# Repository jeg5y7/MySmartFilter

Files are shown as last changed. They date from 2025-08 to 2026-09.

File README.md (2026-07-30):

# MySmartFilter

End-to-end IoT platform for monitoring HVAC air filters. Pairs **ESP32 sensor
hardware** with a **Next.js web app** that visualises live readings, alerts
owners when a filter is loaded, and can auto-order replacements through Stripe.

Hosted at <https://mysmartfilter.com>.

See [ROADMAP.md](./ROADMAP.md) for the path to public launch.

## Features

- **Energy-cost filter model** — blower runtime is detected from ΔP (pressure
  across the filter is ~0 when the blower is off), extra electricity vs. a
  clean-filter baseline is accrued on every reading, and a replacement is
  alerted/auto-ordered once that cost meets the price of the customer's
  preferred filter. ECM (variable-speed) systems only; PSC systems use the
  pressure threshold.
- **Device fleet management** — pair / rename / relocate / delete ESP32 devices
  through a 4-step setup wizard with QR scanning and captive-portal WiFi
  onboarding.
- **Live sensor dashboard** — differential pressure, temperature, humidity, CO₂
  and VOC readings rendered with Recharts (selectable time range, status chips).
- **Filter alerts** — per-device pressure threshold, configurable auto-order
  delay, in-app alert management page.
- **Email notifications** via Resend — device-offline alerts and auto-order
  confirmations with templated HTML.
- **Auto-replenishment** — Stripe Checkout for one-off orders plus a scheduled
  job that opens auto-orders when a filter alert ages past its grace window.
- **Public REST API (`/api/v1/*`)** — Bearer `sk_live_…` keys, managed under
  `/settings`.
- **Outbound webhooks** — HMAC-signed `filter.alert`, `device.offline`, and
  `reading.threshold` events with a delivery log.
- **OTA firmware updates** — `/api/ota/check` + `/api/ota/download` consumed by
  the `esp32-ota` PlatformIO environment.
- **CSV export** — download a device's full reading history.
- **Scheduled jobs** via Vercel Cron — device-offline sweep and auto-order
  processor.

## Stack

| Layer | Tech |
|---|---|
| Framework | Next.js 15 (App Router) + React 19 |
| API | tRPC 11 + TanStack Query, plus REST under `/api/*` |
| Auth | NextAuth v5 (Resend magic-link provider) + Prisma adapter |
| DB | PostgreSQL via Prisma 6 |
| Payments | Stripe Checkout + webhooks |
| Email | Resend |
| Charts / UI  | Recharts, Tailwind v4 |
| Validation | Zod, `@t3-oss/env-nextjs` |
| Firmware | ESP32 / PlatformIO (envs: `esp32-dev`, `-prod`, `-test`, `-ota`) |
| Hosting | Vercel (Hobby plan — crons are daily) |

## Repository layout

```
src/
  app/
    api/
      auth/            NextAuth route handlers
      device/          ESP32 + dashboard device endpoints
      sensor/          Sensor ingest (POST)
      cron/            device-offline, auto-order
      ota/             check, download
      export/          CSV export
      store/           Stripe checkout + webhook
      user/            Account settings
      v1/devices/      Public REST API
      trpc/            tRPC handler
    dashboard/         Authenticated dashboard
    devices/           Device list + detail
    setup/             Device pairing wizard
    settings/          API keys, webhooks, notifications
    store/             Filter shop, orders, success
    signin/            Magic-link sign-in
  server/
    api/routers/       post, sensor, user, device, firmware, integrations
    auth/              NextAuth config + custom Prisma adapter
    db.ts              Prisma client singleton
  lib/                 energy, filter-alerts, filter-preference, api-key,
                       resend, stripe, stripe-client, webhooks
  trpc/                Client / server tRPC plumbing
prisma/
  schema.prisma        Device, SensorReading, FilterAlert, Order, …
  seed.ts              Seed data
esp32/
  platformio.ini       Multi-environment build config
  src/                 Firmware (captive portal, SDP810 driver, main)
```

## Local development

### Prerequisites

- Node 20+ (`package.json` pins `npm@10.9.2`)
- PostgreSQL 15+ — `./start-database.sh` spins up a Docker container
- A Resend account (for sign-in emails)
- A Stripe account (test mode works)

### Setup

```bash
git clone https://github.com/jeg5y7/MySmartFilter.git
cd MySmartFilter
cp .env.example .env          # fill in values, see below
./start-database.sh           # optional Docker postgres
npm install
npm run db:push               # apply Prisma schema
npm run db:seed               # optional seed data
npm run dev                   # http://localhost:3000
```

### Environment variables

Required for the app to boot:

| Variable | Notes |
|---|---|
| `DATABASE_URL` | Postgres connection string |
| `AUTH_SECRET` | `npx auth secret` |
| `RESEND_API_KEY`  | Magic-link sign-in + alert emails  |
| `EMAIL_FROM` | e.g. `noreply@mysmartfilter.com` |

Required for the store and scheduled jobs (all validated in `src/env.js`):

| Variable | Notes |
|---|---|
| `STRIPE_SECRET_KEY` | Server-side Stripe |
| `STRIPE_WEBHOOK_SECRET` | Used by `/api/store/webhook` |
| `NEXT_PUBLIC_STRIPE_PUBLISHABLE_KEY` | Client-side |
| `CRON_SECRET` | Bearer token Vercel sends to crons |
| `NEXTAUTH_URL` / `AUTH_URL` | Base URL for Stripe redirects |

### Useful scripts

```bash
npm run dev          # next dev --turbo
npm run build        # production build
npm run typecheck    # tsc --noEmit
npm run lint         # next lint
npm run check        # lint + typecheck
npm run db:push      # sync schema to DB
npm run db:generate  # prisma migrate dev
npm run db:migrate   # prisma migrate deploy
npm run db:studio    # Prisma Studio UI
npm run db:seed      # run prisma/seed.ts
```

## Firmware

The `esp32/` workspace uses PlatformIO. Select an environment per target:

```bash
cd esp32
pio run -e esp32-dev    # localhost:3000
pio run -e esp32-prod   # mysmartfilter.com
pio run -e esp32-test   # fake sensor data, no hardware
pio run -e esp32-ota    # OTA-capable build
```

The captive-portal flow lets a fresh device be configured from a phone with no
hardcoded credentials. After pairing, the device POSTs to `/api/sensor` using a
Bearer `sf_…` API token issued by `/api/device/register`.

See `esp32/PLATFORMIO_GUIDE.md` for hardware bring-up.

## Deployment

Built for Vercel:

1. Provision a Postgres database (Vercel Postgres / Neon / Supabase).
2. Add the env vars above in **Project Settings → Environment Variables**.
3. Configure a Stripe webhook pointing at `/api/store/webhook` and copy the
   signing secret into `STRIPE_WEBHOOK_SECRET`.
4. Verify the Resend domain — see `RESEND_DNS_SETUP.md` and
   `VERCEL_DNS_RECORDS.md`.
5. Vercel reads `vercel.json` for the cron schedule.

## REST API v1

```
GET /api/v1/devices
Authorization: Bearer sk_live_<hex>
```

Manage keys at `/settings`. Each key tracks `lastUsed` for auditing.

Webhook payloads are signed with HMAC-SHA256:

```
X-SmartFilter-Event: filter.alert
X-SmartFilter-Signature: sha256=<HMAC of body using webhook.secret>
```

## Known issues / TODO

- Crons run daily (Vercel Hobby limit). Handlers are schedule-agnostic, but
  offline alerts and auto-orders can lag up to 24 h — upgrade to Pro and set
  `*/15` / hourly schedules before launch (see ROADMAP Phase 3).
- Auto-orders create `pending` orders but don't charge a card yet — off-session
  Stripe payment is ROADMAP Phase 2.
- Firmware doesn't yet send the `deviceSecret` on register; legacy devices are
  claimable by the first secret presenter (ratchet upgrade path).

## License

Private project — all rights reserved.

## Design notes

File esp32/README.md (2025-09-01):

# Smart Filter Monitor - ESP32 Firmware

This Arduino code monitors your filter's differential pressure using an SDP810 sensor and sends data to mysmartfilter.com for real-time tracking and predictive maintenance.

## Hardware Requirements

- ESP32 DevKit v1
- SDP810 Differential Pressure Sensor
- Jumper wires for I2C connections

## Wiring Diagram

| ESP32 Pin | SDP810 Pin | Description |
|---|---|---|
| 3.3V | VDD | Power supply |
| GND | GND | Ground |
| GPIO 21 | SDA | I2C Data |
| GPIO 22 | SCL | I2C Clock |

## Arduino IDE Setup

1. **Install ESP32 Board Package:**
   - File → Preferences
   - Add this URL to Additional Board Manager URLs:
     ```
     https://dl.espressif.com/dl/package_esp32_index.json
     ```
   - Tools → Board → Boards Manager
   - Search "ESP32" and install "ESP32 by Espressif Systems"

2. **Install Required Libraries:**
   - Sketch → Include Library → Manage Libraries
   - Install these libraries:
     - `ArduinoJson` by Benoit Blanchon
     - `WiFi` (usually pre-installed)
     - `HTTPClient` (usually pre-installed)

## Configuration

### 1. WiFi Settings
Update these lines in `sensor_monitor.ino`:
```cpp
const char* ssid = "Your_WiFi_Name";
const char* password = "Your_WiFi_Password";
```

### 2. User ID Configuration
To get your User ID:

1. **Sign in to your app** at https://mysmartfilter.com
2. **Open browser developer tools** (F12)
3. **Go to Application/Storage → Local Storage**
4. **Look for user session data** or...
5. **Use this temporary method:**

Add this tRPC query to your app to get user IDs:

```typescript
// In your app, add this to get user ID
console.log("User ID:", session?.user?.id);
```

Then update the ESP32 code:
```cpp
const char* userId = "your_actual_user_id_here";
```

### 3. Device ID (Optional)
You can customize the device identifier:
```cpp
const char* deviceId = "SmartFilter_YourLocation";
```

## Upload Instructions

1. **Connect ESP32** to your computer via USB
2. **Select Board:** Tools → Board → ESP32 Dev Module
3. **Select Port:** Tools → Port → (your ESP32 port)
4. **Upload:** Sketch → Upload

## Monitoring

1. **Open Serial Monitor:** Tools → Serial Monitor
2. **Set baud rate to 115200**
3. **Watch for:**
   - WiFi connection status
   - Sensor readings
   - API response messages

## Troubleshooting

### WiFi Issues
- Check SSID and password
- Ensure 2.4GHz WiFi (ESP32 doesn't support 5GHz)
- Check signal strength

### Sensor Issues
- Verify I2C wiring
- Check sensor power (3.3V)
- Try different I2C addresses if needed

### API Issues
- Verify user ID is correct
- Check internet connection
- Monitor serial output for HTTP errors

## Sample Serial Output

```
ESP32 Sensor Monitor Started
Device ID: SmartFilter_001
WiFi connected!
IP address: 192.168.1.100
SDP810 sensor initialized successfully

=== Sensor Reading ===
Pressure: 125.3 Pa
Temperature: 23.5 °C
Sending: {"pressure":125.3,"temperature":23.5,"deviceId":"SmartFilter_001","userId":"user123"}
HTTP Response: 200
Response: {"success":true,"data":{"id":"abc123","timestamp":"2025-08-13T04:00:00.000Z"}}
✓ Data sent successfully
```

## Next Steps

1. **Test locally** with serial monitor
2. **Verify data appears** in your web dashboard
3. **Adjust reading interval** if needed (currently 30 seconds)
4. **Add error handling** for production use

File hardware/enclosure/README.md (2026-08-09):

# Rev A enclosure — 3D-printable

Two variants, both parametric CadQuery models:

- **USB-powered (current pilot direction)** — `enclosure_usb.py` →
  `base-usb.stl` / `lid-usb.stl` / `enclosure-usb.step`.
  **116.8 × 46.8 × 28.4 mm.** No battery bay; the dev board's USB port
  faces a 16 × 10 mm wall opening, so the power cable plugs straight into
  the board. Tubes enter the opposite end.
- **Battery (parked with Rev B firmware)** — `enclosure.py` →
  `base.stl` / `lid.stl` / `enclosure.step`. **136.8 × 60.8 × 31.4 mm**
  with a 3×AA bay and a grommeted power-cable hole.

Everything below applies to both unless noted.

## Print settings (Bambu Studio)

| Setting | Value |
|---|---|
| Material | **PETG** (handles furnace-room temps better than PLA) |
| Layer height | 0.2 mm |
| Walls | 3 |
| Infill | 15 % gyroid |
| Supports | **None needed** |
| Orientation | base: cavity up (as imported) · lid: top face down (as imported) |
| Plate | textured PEI, no brim needed |

Import both STLs into one plate — combined print is roughly 3–4 h on a P1/X1.

## What goes where

- **USB variant power**: route a micro-USB/USB-C cable through the wall
  opening straight into the dev board — no internal power wiring at all
- **Battery bay** (battery variant only — large fence, left): flat 3×AA
  holder (~58×48×16 mm), drops in; dab of hot glue or foam tape to stop
  rattle
- **ESP32 bay** (long fence, front-right): 30-pin dev board drops in flat
- **Sensor bay** (small fence, back-right): SDP810 sits inside; the kit's
  two tubes pass through the **two grommeted holes in the right end wall**
  (Ø7.6 — fits a standard 8 mm rubber grommet with tube through it)
- **Power** (Ø8.2 hole, front wall): adapter cable enters over the ESP32
  bay; knot the cable inside as a strain relief
- **Magnets**: 4 × Ø12×3 mm neodymium discs glue into the pockets on the
  **outside bottom** (CA or E6000, flush = full grip on the furnace cabinet;
  adhesive pad is the backup for non-steel cabinets)
- **Lid**: 12 mm panel-mount momentary button + 5 mm LED press into the two
  lid holes; skirt drops into the cavity; 4 × #4 × ½″ self-tapping screws
  into the corner posts

## Tweaking the fit

Everything is a named parameter at the top of `enclosure.py` (bay sizes,
hole diameters, wall thickness, magnet size…). Change a number, rerun:

```bash
pip install cadquery
python hardware/enclosure/enclosure.py
```

First-print checklist: verify your battery holder and dev-board footprints
against `BAT_L/BAT_W` and `ESP_L/ESP_W` before slicing — clone boards vary
by a millimeter or two.

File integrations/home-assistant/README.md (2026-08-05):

# MySmartFilter × Home Assistant

Brings your smart filter monitor into Home Assistant: filter life, pressure
drop, temperature, battery, wasted-energy cost, and a **Replace filter**
problem sensor you can automate on.

## Install (manual, ~2 minutes)

1. Copy `custom_components/mysmartfilter/` into your Home Assistant
   `config/custom_components/` folder.
2. Restart Home Assistant.
3. **Settings → Devices & Services → Add Integration → MySmartFilter.**
4. Paste an API key from
   [mysmartfilter.com → Settings → Integrations](https://www.mysmartfilter.com/settings/integrations).

Each monitor appears as a device with these entities:

| Entity | What it is |
|---|---|
| `sensor.<name>_filter_life` | % of filter value remaining (100 = fresh) |
| `sensor.<name>_filter_pressure_drop` | Live ΔP across the filter (Pa) |
| `sensor.<name>_temperature` | Utility-room temperature |
| `sensor.<name>_battery` | Battery % (battery models) |
| `sensor.<name>_wasted_energy_cost` | ¢ of extra electricity this filter has cost |
| `sensor.<name>_blower_runtime` | Blower hours on this filter |
| `binary_sensor.<name>_replace_filter` | On when replacement saves money |

## Example automation

```yaml
automation:
  - alias: "Filter needs replacing — light the hallway lamp red"
    trigger:
      - platform: state
        entity_id: binary_sensor.furnace_replace_filter
        to: "on"
    action:
      - service: light.turn_on
        target: { entity_id: light.hallway }
        data: { color_name: red }
```

## Notes

- Cloud-polling every 2 minutes via the public API (`GET /api/v1/devices`).
- Battery monitors upload hourly, so their values step hourly — alerts still
  push to your email/phone immediately via the MySmartFilter cloud.
- HACS: this folder will move to a dedicated repository for HACS listing;
  manual install works today.

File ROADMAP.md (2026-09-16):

# MySmartFilter — Launch Roadmap

**Goal:** public launch in ~3 months.
**Business model:** razor-and-blades with a freemium split — buy the monitor
and get live data free (dashboard + smart home); enroll in **Filter AutoShip**
(automatic filter shipping) to unlock the energy-savings calculation,
historical trending, and advanced HVAC diagnostics (future). No separate
subscription fee — filters are the revenue.
**Fulfillment (launch):** manual dropship from an admin order queue.

## Tier enforcement ✅

- [x] Server-side gates: history queries clamp to a 1-hour live window for
  free accounts (`sensor.getByTimeRange`), CSV export is member-only (403)
- [x] UI: Filter Health card shows a locked/upsell state for free tier;
  chart ranges beyond 1h are locked with an AutoShip hint; Export hidden
- [x] v1 API: `plan` field; energy-model outputs (filterLifePct,
  filterStatus, runtimeHours, extraEnergyCostCents) are null on free —
  HA integration degrades gracefully (live sensors work, premium unknown)
- [x] Device LED: button press replays server's filter verdict (solid =
  OK, 3 slow blinks = soon, 6 fast = replace) cached from batch responses

## Phase 0 — Production blockers ✅

- [x] Delete unauthenticated `GET /api/sensor` and `/api/debug-env`
- [x] Validate Stripe/cron env vars through `src/env.js`
- [x] Remove public `sensor.create` tRPC mutation (unauthenticated write)
- [x] `/api/device/register` token leak — device-secret handshake
  (firmware presents a self-generated secret to re-fetch its token)
- [x] Offline sweep made schedule-agnostic (works on daily Hobby cron)
- [x] Fix filter-preference resolution (device-specific → user default)

## Phase 1 — Energy-cost model ✅

The core product promise: replace the filter when the extra electricity it
burns exceeds the price of a new one.

- [x] `src/lib/energy.ts` — physics: `extraWatts = ΔP_rise × airflow / η`,
  blower runtime detected from ΔP > 5 Pa (pressure is ~0 when the blower is off)
- [x] Per-reading accrual of runtime + extra cost on ingest
- [x] Clean-filter baseline auto-captured on first blower-on reading
- [x] Energy-cost alert → email → 24 h grace → auto-order — both blower
  types: ECM accrues direct extra blower watts; PSC accrues the
  system-runtime penalty (less airflow → less capacity → compressor and all
  run longer to satisfy the thermostat)
- [x] HVAC settings UI (blower type, airflow CFM, electricity rate)
- [x] Filter Health card with cost-vs-price progress meter
- [x] "I replaced my filter" reset flow

**Deploy note:** run `npm run db:push` (or a migration) — `Device` gained
`deviceSecretHash`, `blowerType`, `airflowCfm`, `electricityRateCents`,
`baselineDeltaP`, `filterInstalledAt`, `runtimeHours`,
`extraEnergyCostCents`, `lastAccrualAt`.

## Phase 2 — Money movement ✅

- [x] Saved payment methods: checkout saves the card
  (`setup_future_usage: off_session`), `/settings/billing` adds one without a
  purchase (setup-mode Checkout), webhook stores the payment method
- [x] Off-session PaymentIntent in the auto-order cron — auto-orders charge
  the card on file; declined cards → `payment_failed` + fix-it email
- [x] Shipping address on file (auto-captured from checkout, editable at
  `/settings/billing`)
- [x] Admin role + `/admin/orders` queue: ready-to-ship list with items/SKU +
  address, mark-shipped with tracking → customer email
  (`npx tsx scripts/make-admin.ts <email>` grants access)
- [x] One-click tokenized cancel link in alert emails (`/api/alert/cancel`)

**Deploy note:** `npm run db:push` again — `User` gained billing/shipping
columns, `Order` gained tracking fields, `FilterAlert` gained `cancelToken`.
Also removed the committed `.env.production` — **rotate the Neon database
password and Stripe webhook secret**, both were in git history.

## Phase 3 — Launch surface ✅ (one founder decision open)

- [x] Landing page: hero rewritten around the energy-cost pitch, footer with
  real links (was dead `#` links + a fake subscribe form)
- [x] Terms of Service (`/terms`) + Privacy Policy (`/privacy`) — drafts,
  founder should read before launch
- [x] Rate limiting on `/api/sensor`, `/api/device/register`, `/api/v1/*`,
  `/api/alert/cancel` (in-memory per-instance — swap for Upstash at scale)
- [ ] **Founder decision:** Vercel Pro + crons back to `*/15` and hourly
- [x] `/install` customer installation guide — diagrams of the four common
  HVAC layouts, universal tap rules, safety cautions; "Installation" nav tab
- [x] Furnace make/model per device (HVAC settings card + profile list)
- [x] PWA manifest + generated icons — dashboard installs on phones
- [x] Welcome email on signup (NextAuth createUser event)
- [x] Stopped logging device tokens in the sensor route

## Phase 4 — Hardware launch checklist

Software side can spec; physical work is on the founder:

- [ ] Lock BOM: ESP32 module (pre-certified, e.g. ESP32-WROOM-32E) + Sensirion
  SDP810-500 + enclosure + tubing/ports
- [x] Firmware: device-secret handshake written (generated from hardware RNG
  on first boot, stored in EEPROM config, sent on `/api/device/register`) —
  **needs a hardware flash + test before the pilot batch**
- [x] Hardware Rev A design doc: 3×AA + TPS63031 buck-boost wiring, enclosure
  concept, magnet-primary mounting, ~$47 pilot BOM (artifact "Hardware Rev A")
- [x] Printable enclosure CAD (`hardware/enclosure/` — parametric CadQuery
  source + STLs + STEP; PETG, no supports). **Pilot decision: USB-powered
  variant** (`*-usb.stl`, plug-through wall opening, no battery bay, no
  TPS63031) — simpler, cheaper (~$8–10/unit less), matches the "plug in
  the power adapter" site copy. Battery variant + Rev B firmware stay in
  the repo for a future battery SKU. **Founder: print the USB variant and
  fit-check the dev board before the pilot run**
- [x] Battery architecture backend: `POST /api/sensor/batch` (sample locally,
  upload hourly with age-offset timestamps, exception-push on alerts),
  `Device.batteryPct` + low-battery email, cadence-aware offline detection
  (3 missed check-ins) — **prod needs 2-column ALTER before deploy**
- [x] Deep-sleep batch firmware (Rev B) — compile-verified with the real ESP32
  toolchain (RAM 14.8%, flash 77%); needs a hardware flash test before pilot
- [ ] QR label workflow: deviceId printed at flash time, QR resolves to
  `mysmartfilter.com/setup?device=<id>`
- [ ] FCC: unintentional-radiator route using the module's modular cert
- [ ] Install kit: filter-slot mounting, upstream/downstream pressure taps
- [ ] Pilot batch (~25 units) before public sale

## Smart-home bridge ✅ (software) — founder: platform accounts

- [x] OAuth2 account-linking server: consent screen (`/oauth/authorize`),
  token endpoint (auth-code + refresh grants), hashed secrets/tokens,
  `scripts/create-oauth-client.ts` to mint per-platform credentials
- [x] Normalized bridge API (`/api/bridge/devices`) with tier rules intact
- [x] Google Home cloud-to-cloud fulfillment (`/api/bridge/google` —
  SENSOR + SensorState: FilterCleanliness/FilterLifeTime)
- [x] SmartThings Schema connector (`/api/bridge/smartthings` — filterStatus,
  temperature, battery, healthCheck)
- [x] Alexa Smart Home lambda (`integrations/alexa/lambda/`) → bridge API
- [ ] **Founder:** create the three free developer accounts and paste in
  URLs/credentials — step-by-step in `docs/smart-home-bridge.md`
- [ ] Proactive state push + "Works with" certifications (during cert phase)

## Advanced HVAC diagnostics (premium tier — needs pilot data first)

- **Cycle-performance trending:** we already record temperature + blower
  state every 30 s, so each heating/cooling cycle yields "minutes to move
  the return air X degrees." Trending that per-cycle rate over months
  reveals declining capacity (dirty filter, low refrigerant, failing
  compressor) — but it MUST be weather-normalized (outdoor temp / degree
  days are the dominant confounder; naive trending false-alarms every heat
  wave). Cross-validates the PSC runtime-penalty model with measured data.
  Plan: per-cycle summary extraction server-side once pilot data exists.
- **Weather + runtime correlation (data groundwork):** SHIPPED first slice
  2026-09-16 — DeviceLocation geocoding (Census oneline → Open-Meteo zip
  fallback, self-provisioned table) + on-demand Open-Meteo hourly fetch
  powering a toggleable outdoor temp/humidity overlay on the device charts
  (hourly lines on live views, daily MAX on 7d/30d; Open-Meteo attribution
  in UI). Still to come: nightly stored pulls per grid cell (apparent temp /
  cloud cover / radiation) → join against runtime-per-day. Unlocks weather-normalized filter
  trending and the four derived diagnostics: ΔP plateau (runtime-normalized),
  runtime vs degree-days, within-run ΔP sag (coil wetness — measured at
  ~1.3 Pa on the pilot; extreme sag = icing early-warning), and pull-down
  rate (°F/hr while running = delivered capacity).
- **Google Nest sandbox integration (pilot instrument):** SDM API exposes
  indoor humidity (Humidity trait) + thermostat state. Sandbox tier = $5
  one-time, 25 users / 5 homes cap — perfect for validating the sag↔indoor-RH
  correlation on the pilot before Rev B ships its own RH chip. Commercial
  tier needs Google certification (security assessment) — NOT a launch
  dependency; revisit only if diagnostics headline demands it.
  **LIVE 2026-09-16:** founder completed Device Access registration +
  OAuth client and connected the pilot Nest — humidity samples flowing
  ~every 5 min (see docs/NEST_SANDBOX.md for the setup + gotchas).
  Next: after ~2 weeks of humid/dry contrast, correlate within-run ΔP
  sag vs indoor RH (add a NestSample read endpoint for analysis then).
- **RH chip on Rev B — PROMOTED from candidate to planned:** a ~$2 humidity
  sensor measuring the actual return-air stream (better placement than any
  wall thermostat) on every unit, no third-party OAuth, no user caps. The
  coil-wetness / latent-load science the Nest pilot validates runs fleet-wide
  on this.
- **Acoustic anomaly detection (Rev B hardware):** ~$0.50 MEMS mic on the
  monitor. On-device feature extraction only (band energies/levels — NEVER
  raw audio off the device; privacy stance worth advertising). Learn each
  home's baseline sound signature; alert on deviation (bearing whine, belt
  squeal, rattle, short-cycling). Long-term: fleet-wide failure signatures
  = "your blower motor sounds like ones that failed within 60 days."

## Later / ideas

- 📷 Furnace-label photo identification (Claude vision reads the rating plate
  → auto-fills make/model/blower/airflow). Built once and parked by founder
  decision — restore from PR #13 history (commit b278ec4: identify-furnace
  route + photo UI in device-settings) and add `ANTHROPIC_API_KEY` in Vercel.
- HVAC troubleshooting insights (short-cycling detection from runtime patterns,
  frozen-coil signature: rising ΔP with falling supply temperature)
- Native mobile app (React Native/Expo) once PWA outgrows itself
- Distributor/3PL integration when manual dropship exceeds ~50 orders/mo
- Multi-tenant / property-manager accounts (many devices, one payer)

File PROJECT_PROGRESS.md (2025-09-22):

# Smart Filter Monitoring System - Project Progress

## Session Date: January 2, 2025

## 🎯 What We Accomplished

### 1. ✅ Database Schema - Device Management System
**Location:** `/prisma/schema.prisma`

Added three new models to support multi-device management:
- **Device Model** - Tracks devices with unique IDs, API tokens, status, firmware version
- **ProvisioningSession Model** - Manages device setup sessions with temporary tokens
- **Updated Relations** - Connected devices to users and sensor readings

**Key Features:**
- Each device gets a unique API token for authentication
- Devices can exist without users (pending state)
- Provisioning sessions expire after 10 minutes
- Device status tracking (active, offline, pending, error)

### 2. ✅ API Endpoints - Complete Device Management
**Location:** `/src/app/api/device/`

Created 9 API endpoints for device management:

#### Device Registration & Linking
- `POST /api/device/register` - ESP32 calls to get API token
- `POST /api/device/link` - User links device to account
- `POST /api/device/provision` - Start provisioning session
- `PUT /api/device/provision` - Complete provisioning

#### Device Management
- `GET /api/device/list` - List all user devices
- `GET /api/device/[deviceId]` - Get device details
- `PUT /api/device/[deviceId]` - Update device info
- `DELETE /api/device/[deviceId]` - Remove device
- `PUT /api/device/status` - Device updates its status

#### Updated Sensor Endpoint
- `POST /api/sensor` - Now uses Bearer token authentication
  - No longer needs userId in request
  - Device identified by API token
  - Updates device last seen time

### 3. ✅ ESP32 Firmware - Professional Setup
**Location:** `/esp32/`

Created multiple versions of ESP32 firmware:

#### Arduino IDE Sketches (.ino files)
1. **smart_filter_wifimanager.ino** - Full WiFi Manager with captive portal
2. **smart_filter_simple.ino** - Hardcoded credentials version
3. **connection_test.ino** - Basic connectivity test

#### PlatformIO Professional Setup
1. **Installed PlatformIO** via Homebrew
2. **Created main.cpp** - Professional multi-environment firmware
3. **Configured platformio.ini** with environments:
   - `esp32-dev` - Local development (10.0.0.21:3000)
   - `esp32-prod` - Production (mysmartfilter.com)
   - `esp32-test` - Test mode with fake sensor data
   - `esp32-ota` - Over-the-air updates

**Features:**
- Auto device registration
- Token-based authentication
- Factory reset (hold BOOT button 5 seconds)
- LED status indicators
- Automatic reconnection
- Error recovery

### 4. ✅ Development Tools Setup
- **PlatformIO installed and configured**
- **Multiple build environments**
- **VS Code integration ready**
- **Test environment works without hardware**

## 📁 File Structure Created

```
sensor-monitoring/
├── prisma/
│   └── schema.prisma (Updated with Device, ProvisioningSession)
├── src/app/api/
│   ├── device/
│   │   ├── register/route.ts
│   │   ├── link/route.ts
│   │   ├── provision/route.ts
│   │   ├── status/route.ts
│   │   ├── list/route.ts
│   │   └── [deviceId]/route.ts
│   └── sensor/route.ts (Updated for token auth)
├── esp32/
│   ├── src/
│   │   └── main.cpp (PlatformIO version)
│   ├── platformio.ini (Multi-environment config)
│   ├── smart_filter_wifimanager.ino
│   ├── smart_filter_simple.ino
│   ├── connection_test.ino
│   └── PLATFORMIO_GUIDE.md
└── PROJECT_PROGRESS.md (This file)
```

## 🔑 Key Technical Decisions

1. **Database:** PostgreSQL with Prisma ORM
2. **Authentication:** Bearer tokens for devices (format: `sf_[64-char-hex]`)
3. **Device IDs:** Format `SF[14-random-alphanumeric]` (e.g., SF1234567890ABCD)
4. **ESP32 Development:** PlatformIO over Arduino IDE for production
5. **API Design:** RESTful with device self-registration

## 🚀 How to Resume Development

### 1. Start Your Local Server
```bash
cd /Users/jongoecker/Projects/sensor-monitoring
npm run dev
# Server runs at http://localhost:3000
```

### 2. Test Device Registration (No Hardware Needed)
```bash
# Register a test device
curl -X POST http://localhost:3000/api/device/register \
  -H "Content-Type: application/json" \
  -d '{"deviceId": "SF_TEST_001", "type": "SmartFilter", "firmware": "1.0.0"}'

# Save the token from response!
```

### 3. Test ESP32 Code (Without Hardware)
```bash
cd esp32
# This uses fake sensor data - no hardware needed
platformio run -e esp32-test -t upload -t monitor
```

### 4. Test with Real ESP32
```bash
# Update WiFi credentials in src/main.cpp (line 115-118)
# Then upload
platformio run -e esp32-dev -t upload -t monitor
```

## 📋 Next Steps When You Return

### Immediate Tasks:
1. **Test the system end-to-end**
   - Start dev server
   - Upload ESP32 code
   - Verify data flow

2. **Create UI for device management**
   - Device list page
   - Device detail view
   - Add device wizard
   - Device settings

3. **Add data visualization**
   - Real-time pressure/temperature graphs
   - Historical data views
   - Device status dashboard

### Future Enhancements:
- Push notifications for device offline
- Filter replacement reminders
- OTA firmware updates
- Multiple sensor support per device
- Data export functionality
- Mobile app

## 🔧 Quick Commands Reference

### Database
```bash
# View/edit database
npx prisma studio

# Update schema after changes
npx prisma db push
```

### ESP32 Development
```bash
# Build firmware
platformio run -e esp32-dev

# Upload to ESP32
platformio run -e esp32-dev -t upload

# Monitor serial output
platformio run -e esp32-dev -t monitor

# Test without hardware
platformio run -e esp32-test -t upload -t monitor
```

### API Testing
```bash
# Register device
curl -X POST http://localhost:3000/api/device/register \
  -H "Content-Type: application/json" \
  -d '{"deviceId": "TEST001", "type": "SmartFilter", "firmware": "1.0.0"}'

# Send sensor data (use token from registration)
curl -X POST http://localhost:3000/api/sensor \
  -H "Content-Type: application/json" \
  -H "Authorization: Bearer sf_YOUR_TOKEN_HERE" \
  -d '{"pressure": 12.5, "temperature": 23.4}'
```

## 💡 Important Notes

1. **Your local IP:** 10.0.0.21 (hardcoded in ESP32 dev environment)
2. **Domain:** mysmartfilter.com (DNS points to 216.198.79.1, needs updating for Vercel)
3. **Database:** Local PostgreSQL on port 5432
4. **PlatformIO:** Installed via Homebrew, ready to use
5. **Test Mode:** Works without sensor hardware (generates fake data)

## ✅ System Status

- **Backend API:** Complete and tested ✅
- **Database Schema:** Updated and migrated ✅
- **ESP32 Firmware:** Multiple versions ready ✅
- **Development Environment:** PlatformIO configured ✅
- **Authentication:** Token-based system implemented ✅
- **Multi-device Support:** Fully implemented ✅

## 🎉 Ready to Continue!

Everything is saved and ready for you to pick up where we left off. The system is fully functional for:
- Registering multiple devices
- Authenticating devices with tokens
- Collecting sensor data
- Managing device lifecycle

When you're ready to continue, just:
1. Start your dev server
2. Connect your ESP32
3. Upload the code
4. Watch the data flow!

---
*Session saved: January 2, 2025*
*All code committed and ready for next session*

## Session Update: September 09, 2025

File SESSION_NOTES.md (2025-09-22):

# Session Notes - Smart Filter Monitoring

## Current Session: January 10, 2025

### ✅ Completed Today:
- [x] Built complete device management UI
- [x] Fixed authentication issues with magic links
- [x] Created device list component with full CRUD operations
- [x] Added SessionProvider for proper auth context
- [x] Linked test device to user account
- [x] Tested end-to-end flow successfully

### What I'm Working On:
- [ ] Adding data visualization for sensor readings
- [ ] Creating device detail pages
- [ ] Implementing real-time sensor data updates

### Last Actions Taken:
- Fixed NextAuth magic link authentication error
- Created custom Prisma adapter to handle session issues
- Added SessionProvider to app layout
- Created device management page at /devices
- Created DeviceList component with status indicators
- Added navigation from dashboard to device management
- Linked demo device to user account
- Server running at http://localhost:3000
- Prisma Studio at http://localhost:5555

### Important Context:
- Local IP: 10.0.0.21
- Dev server: http://localhost:3000
- ESP32 environments configured in platformio.ini
- Token format: sf_[64-char-hex]
- Device ID format: SF[14-char-alphanumeric]

### Commands to Resume:
```bash
# Start dev server
npm run dev

# Test ESP32 without hardware
cd esp32 && platformio run -e esp32-test -t monitor

# View database
npx prisma studio
```

### Next Steps:
1. Test device registration flow
2. Verify sensor data submission
3. Start on UI components

### Questions/Issues to Resolve:
- None currently

### Useful References:
- API endpoints in /src/app/api/device/
- ESP32 code in /esp32/src/main.cpp
- Schema in /prisma/schema.prisma

---
*Update this file at the end of each session*

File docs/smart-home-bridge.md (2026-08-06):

# Smart-home bridge — founder setup guide

The software side of "Works with Google Home / Alexa / SmartThings" is live:
an OAuth2 account-linking server plus one connector endpoint per platform.
What remains is creating the (free) developer accounts on each platform and
pasting in URLs + credentials. Each platform takes roughly an evening; all
three can be done independently, in any order.

## How it fits together

```
Google/Alexa/SmartThings app ──"link account"──▶ mysmartfilter.com/oauth/authorize
        (user clicks Allow; platform receives an access token)
Google  ──POST /api/bridge/google       (SYNC/QUERY intents)
Alexa   ──AWS Lambda──▶ GET /api/bridge/devices
SmartThings ──POST /api/bridge/smartthings  (discovery/state)
```

Tier rules carry through automatically: everyone gets live temperature,
online status, and battery; Filter AutoShip members also get filter health
(life % + clean/dirty/replace states).

## Step 0 — mint one OAuth client per platform

Run once per platform (from the repo, with `DATABASE_URL` pointed at prod),
substituting the platform's redirect URI (each platform shows you theirs
during setup):

```bash
npx tsx scripts/create-oauth-client.ts "Google Home" <google-redirect-uri>
npx tsx scripts/create-oauth-client.ts "Alexa" <alexa-redirect-uri-1> <uri-2> <uri-3>
npx tsx scripts/create-oauth-client.ts "SmartThings" <smartthings-redirect-uri>
```

Copy the printed `client_id` / `client_secret` into the platform console.
The secret is shown once and only a hash is stored. Every platform gets the
same two URLs:

- **Authorization URL:** `https://www.mysmartfilter.com/oauth/authorize`
- **Token URL:** `https://www.mysmartfilter.com/api/oauth/token`

## Google Home (cloud-to-cloud)

1. [console.home.google.com](https://console.home.google.com) → create a
   project → "Cloud-to-cloud" integration.
2. Fulfillment URL: `https://www.mysmartfilter.com/api/bridge/google`
3. Account linking: OAuth authorization code; paste the URLs above + the
   client credentials from Step 0 (Google shows its redirect URI — use it
   when minting the client).
4. Test with your own Google account ("Test" in the console), then request
   certification when ready to launch publicly.

## Alexa (Smart Home Skill)

Alexa requires the skill logic to run in AWS Lambda (their rule, not ours) —
the function is already written at `integrations/alexa/lambda/index.mjs`.

1. [developer.amazon.com/alexa](https://developer.amazon.com/alexa) → create
   a **Smart Home** skill.
2. [AWS Lambda](https://console.aws.amazon.com/lambda) → create function,
   Node.js 20.x, paste `index.mjs` (no dependencies), add the "Alexa Smart
   Home" trigger with your skill ID.
3. Put the Lambda ARN into the skill's endpoint config.
4. Account linking: auth-code grant, the two URLs above + Step-0
   credentials (Alexa lists three redirect URLs — pass all three when
   minting the client).
5. Enable the skill on your own Alexa account to test discovery.

## SmartThings (ST Schema)

1. [smartthings.developer.samsung.com](https://smartthings.developer.samsung.com)
   → Developer Workspace → new project → "Device Integration" →
   **SmartThings Schema**.
2. Webhook endpoint: `https://www.mysmartfilter.com/api/bridge/smartthings`
3. Account linking: the two URLs + Step-0 credentials.
4. Device capabilities to declare in the device profile: Filter Status,
   Temperature Measurement, Battery, Health Check.
5. Test via the SmartThings app's "My Testing Devices".

## What's deferred (by design)

- **Proactive state push** (Google Report State / Alexa proactive events /
  ST callbacks): connectors currently answer when polled, which all three
  platforms support. Push needs per-platform service credentials — wire it
  up during certification if required.
- **"Works with" certification** for public listing — each platform's
  console has a submission flow; do this after pilot hardware exists.

## Troubleshooting

- "Can't link accounts" on the consent screen → redirect URI mismatch: the
  URI the platform sent isn't in the client's allowlist. Re-mint the client
  with the exact URI shown in the platform console.
- Token endpoint 401 → wrong client_id/secret pasted into the platform.
- Devices missing filter health → that account isn't a Filter AutoShip
  member; live sensors still work (this is the tier model working).

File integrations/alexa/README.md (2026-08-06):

# Alexa Smart Home Skill

Alexa smart-home skills must run through an AWS Lambda function (Amazon's
requirement). The function in `lambda/index.mjs` is the complete skill
backend: it translates Alexa directives into calls to the MySmartFilter
bridge API (`GET /api/bridge/devices`) using the account-linking token
Alexa supplies.

Setup steps (developer account, Lambda creation, account linking): see
`docs/smart-home-bridge.md` at the repo root.

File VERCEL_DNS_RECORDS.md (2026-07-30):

# DNS Records to Add in Vercel Dashboard

## Go to: https://vercel.com/dashboard/domains/mysmartfilter.com

Click on your domain, then add these records:

### 1. SPF Record (TXT)
- **Name/Host:** @ (or blank for root domain)
- **Type:** TXT
- **Value:** `v=spf1 include:_spf.resend.com ~all`
- **TTL:** 3600 (or Auto)

### 2. DKIM Record (TXT)
- **Name/Host:** `resend._domainkey`
- **Type:** TXT
- **Value:** copy the FULL value from the Resend dashboard. It is ~218
  characters, starts with `p=MIGf`, and must end with `IDAQAB`.
- **TTL:** 60

> ⚠️ **Incident note (2026-07-30):** this record was once pasted truncated
> (108 of 218 chars), which silently broke ALL outbound email — magic links,
> alerts, order confirmations — until Resend's domain check was investigated.
> After adding/editing this record, always confirm at
> https://resend.com/domains that the domain status is **Verified**, and check
> the resolved value ends in `IDAQAB`:
> `https://dns.google/resolve?name=resend._domainkey.mysmartfilter.com&type=TXT`

### 3. Verify
- In Resend → Domains → mysmartfilter.com → click **Verify DNS Records**
- All three records must show green before any email will send.

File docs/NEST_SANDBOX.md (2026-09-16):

# Google Nest sandbox setup (founder, one time, ~20 minutes)

The app side is fully built: OAuth connect/callback routes, encrypted token
storage, a 5-minute humidity poller that rides along with sensor ingestion,
and a "Google Nest" card on Settings → Integrations. It stays invisible until
the three environment variables at the bottom exist. Everything below happens
in the browser on Google's side.

Use your regular **personal Gmail account** for all of it (Google requires a
consumer account, not a Workspace one, and it can't be changed later).

## 1. Create a Google Cloud project (free)

1. Go to https://console.cloud.google.com/projectcreate — name it
   `mysmartfilter-nest`, click **Create**.
2. In the search bar at the top, type **Smart Device Management API**, open
   it, click **Enable**. (This just switches the API on for your project.)

## 2. Create the OAuth client (what our site uses to ask permission)

1. Go to https://console.cloud.google.com/apis/credentials/consent —
   choose **External**, fill in only the required fields (app name
   `MySmartFilter`, your email twice), **Save and continue** through the
   rest. Add yourself under **Test users**.
2. Go to https://console.cloud.google.com/apis/credentials → **Create
   credentials → OAuth client ID** → Application type **Web application**.
3. Name: `MySmartFilter web`. Under **Authorized redirect URIs** click
   **Add URI** and paste exactly:
   `https://www.mysmartfilter.com/api/nest/callback`
4. Click **Create**. A box shows a **Client ID** (ends in
   `.apps.googleusercontent.com`) and a **Client secret** — keep this tab
   open, you'll paste both into Vercel in step 4.

## 3. Register for Device Access ($5, one time)

1. Go to https://console.nest.google.com/device-access/ → **Get started** —
   accept the terms and pay the one-time $5 fee.
2. Click **Create project** — name it `MySmartFilter pilot`.
3. When it asks for an **OAuth client ID**, paste the Client ID from step 2.
4. Enable events can be skipped (we poll; no Pub/Sub needed).
5. The project page shows a **Project ID** (a UUID like
   `1e2f3a4b-…`). Copy it.

## 4. Add the three values in Vercel

1. Go to https://vercel.com → my-smart-filter project → **Settings →
   Environment Variables**, add these three (environment: Production):
   - `NEST_SDM_PROJECT_ID` — the Device Access Project ID from step 3
   - `NEST_OAUTH_CLIENT_ID` — the Client ID from step 2
   - `NEST_OAUTH_CLIENT_SECRET` — the Client secret from step 2
2. Redeploy (Deployments → ⋯ on the latest → Redeploy) so the app picks
   them up.

## 5. Connect your Nest

1. On mysmartfilter.com go to **Settings → Integrations** — a "Google Nest"
   card now appears. Click **Connect Google Nest**.
2. Google walks you through choosing your home and thermostat and granting
   access ("Allow MySmartFilter to see your thermostat"). Sign in with the
   same Google account your Nest lives on.
3. Back on the Integrations page you'll see live indoor humidity, indoor
   temp, and whether the system is heating/cooling. From then on a sample is
   stored about every 5 minutes whenever the monitor is reporting.

## Notes

- **Sandbox limits:** 25 users across 5 homes — pilot-only by design. The
  fleet answer is the Rev B humidity chip (see ROADMAP.md); commercial Nest
  certification is deliberately not a launch dependency.
- **Privacy/security:** read-only scope; we store the OAuth refresh token
  AES-256-GCM encrypted and never log it. Disconnect (Integrations page)
  deletes the token immediately.
- **Troubleshooting:** "Connection didn't complete" usually means the
  redirect URI in step 2.3 doesn't exactly match, or your Google account
  isn't listed as a Test user on the consent screen.
- **"Error 403: access_denied — has not completed the Google verification
  process":** the account you signed in with isn't on the consent screen's
  **Test users** list. Fix: console.cloud.google.com → APIs & Services →
  OAuth consent screen (aka Google Auth Platform → Audience) → Test users →
  **+ Add users** → add the exact Google account the Nest lives on (family/
  shared accounts count — add whichever one you pick on Google's account
  chooser) → Save → retry Connect.
- **7-day token expiry in Testing mode:** while publishing status is
  "Testing", Google expires refresh tokens after 7 days, so the humidity
  feed silently stops weekly. After the first successful connect, click
  **Publish app** on the consent screen (status "In production"). Skip
  verification — the only effect is a one-time "Google hasn't verified this
  app" warning during connect (Advanced → Go to mysmartfilter.com), which is
  expected for a private pilot app. Tokens then last until revoked.

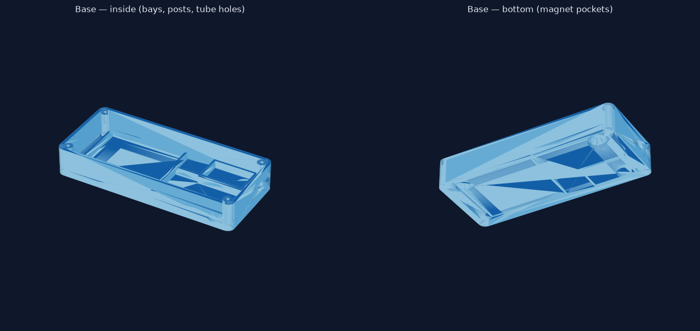
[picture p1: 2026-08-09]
hardware/enclosure/render-base.png

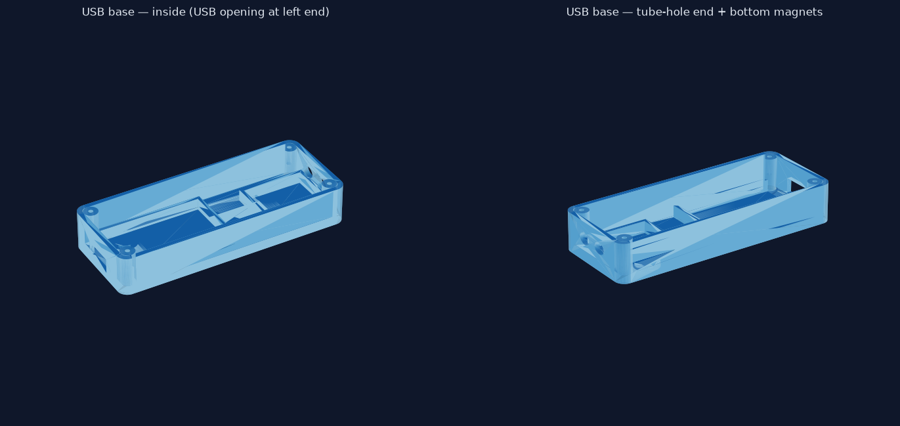
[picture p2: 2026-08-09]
hardware/enclosure/render-base-usb.png

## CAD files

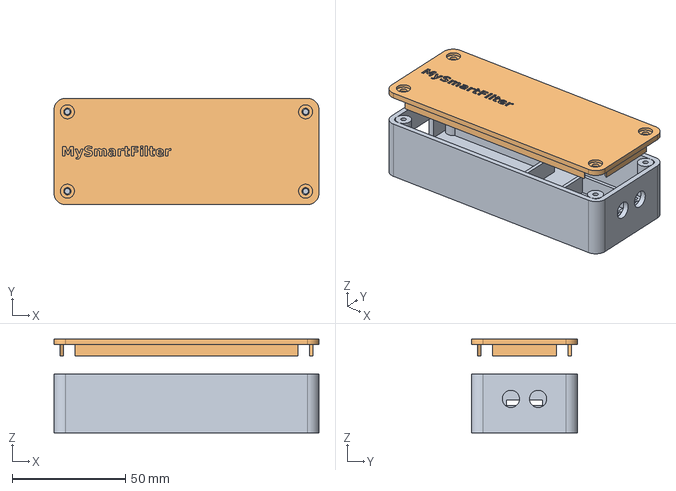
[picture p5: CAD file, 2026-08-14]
hardware/enclosure/enclosure-usb.step
116.8 x 46.8 x 41.4 mm
base
lid

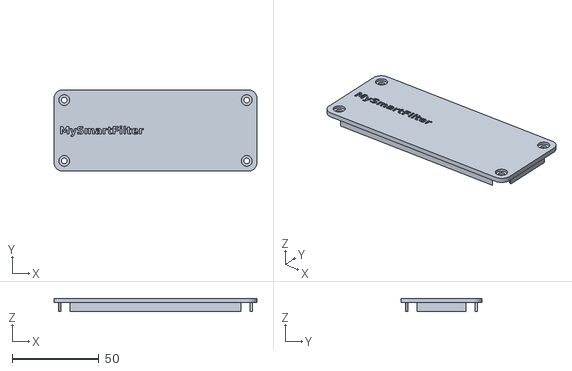
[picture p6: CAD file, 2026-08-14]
hardware/enclosure/lid-usb.stl
116.8 x 46.8 x 7.40

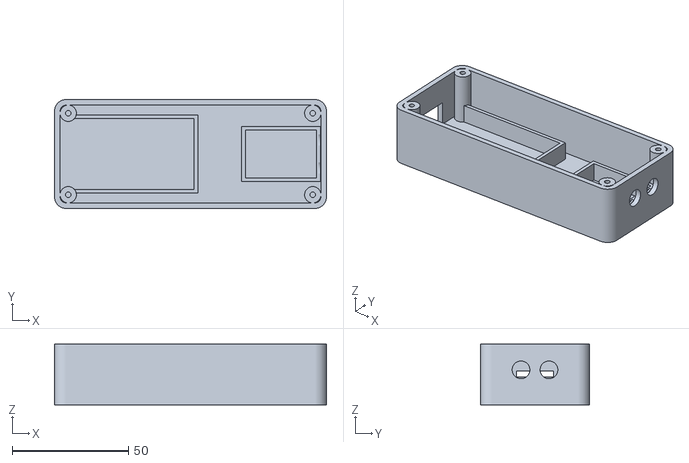
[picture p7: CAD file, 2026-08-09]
hardware/enclosure/base-usb.stl
116.8 x 46.8 x 26.0

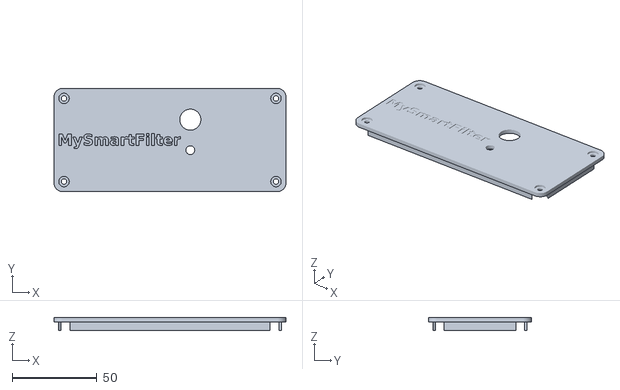
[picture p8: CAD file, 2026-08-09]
hardware/enclosure/lid.stl
136.8 x 60.8 x 7.40

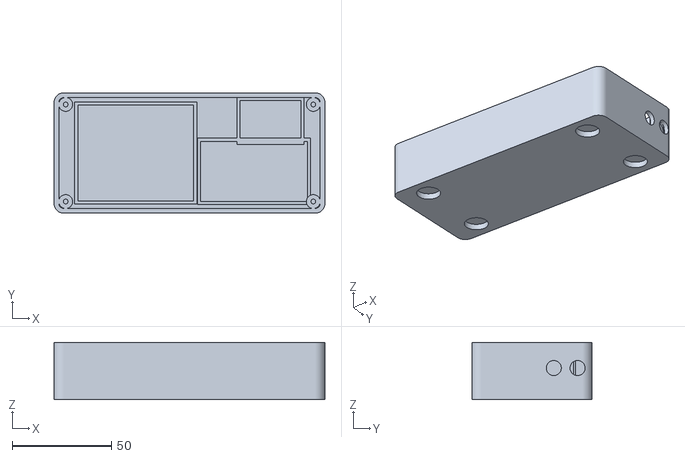
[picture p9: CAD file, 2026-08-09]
hardware/enclosure/base.stl
136.8 x 60.8 x 29.0

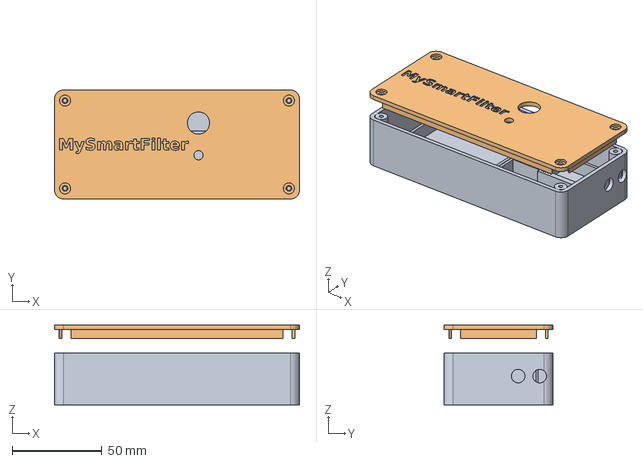
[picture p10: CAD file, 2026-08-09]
hardware/enclosure/enclosure.step
136.8 x 60.8 x 44.4 mm
base
lid

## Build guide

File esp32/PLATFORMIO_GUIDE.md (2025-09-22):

# PlatformIO Development Guide

## Why PlatformIO Over Arduino IDE?

### For Development & Testing:
✅ **Version Control** - All config in text files (platformio.ini)
✅ **Multiple Environments** - Dev/Test/Prod configurations
✅ **Better IDE** - VS Code with IntelliSense, debugging
✅ **Dependency Management** - Libraries versioned and auto-installed
✅ **Command Line** - Scriptable builds for CI/CD
✅ **Faster Compilation** - Only recompiles changed files

### For Production:
✅ **Reproducible Builds** - Exact library versions locked
✅ **CI/CD Integration** - GitHub Actions, GitLab CI support
✅ **OTA Updates** - Built-in over-the-air update support
✅ **Multiple Boards** - Easy to support different hardware
✅ **Professional Debugging** - JTAG, Serial debugging
✅ **Unit Testing** - Built-in test framework

## Quick Commands

### Building
```bash
# Build for development (local server)
platformio run -e esp32-dev

# Build for production
platformio run -e esp32-prod

# Build for testing (no sensor required)
platformio run -e esp32-test

# Clean build files
platformio run -t clean
```

### Uploading to ESP32
```bash
# Upload to ESP32 (auto-detects port)
platformio run -e esp32-dev -t upload

# Upload to specific port
platformio run -e esp32-dev -t upload --upload-port /dev/tty.usbserial-0001

# Upload and monitor
platformio run -e esp32-dev -t upload -t monitor
```

### Monitoring
```bash
# Monitor serial output
platformio run -e esp32-dev -t monitor

# Monitor with custom baud rate
platformio device monitor -b 115200
```

### Testing Without Hardware
```bash
# Use test environment (generates fake sensor data)
platformio run -e esp32-test -t upload -t monitor
```

## VS Code Integration

1. **Install PlatformIO IDE Extension**
   - Open VS Code
   - Install "PlatformIO IDE" extension
   - Restart VS Code

2. **Open Project**
   - File → Open Folder → Select `/esp32` folder
   - PlatformIO will auto-detect project

3. **Use GUI Controls**
   - Bottom toolbar shows:
     - ✓ Build
     - → Upload
     - 🗑 Clean
     - 📟 Serial Monitor
     - 🏠 PlatformIO Home

## Environment Configuration

### Current Environments:

| Environment | API Server | Debug | Sensor | Use Case |
|---|---|---|---|---|
| esp32-dev | Local (10.0.0.21:3000) | Yes | Yes | Development |
| esp32-prod | Production (mysmartfilter.com) | No | Yes | Production |
| esp32-test | Local | Yes | No (Fake) | Testing without hardware |

### Switching Environments:
```bash
# For local development
platformio run -e esp32-dev -t upload

# For production
platformio run -e esp32-prod -t upload

# For testing
platformio run -e esp32-test -t upload
```

## Setting Up Your Device

### 1. First Time Setup
```bash
# 1. Edit src/main.cpp or use WiFi Manager version
# 2. Set your WiFi credentials in config
# 3. Build and upload
platformio run -e esp32-dev -t upload -t monitor
```

### 2. Register Device
The device will auto-register on first boot and save the API token.

### 3. Factory Reset
Hold BOOT button for 5 seconds to clear all settings.

## Library Management

### Current Libraries:
- ArduinoJson 7.0.4 - JSON parsing
- Built-in: WiFi, HTTPClient, Wire, EEPROM

### Adding New Libraries:
```bash
# Search for libraries
platformio lib search "library name"

# Install library
platformio lib install "bblanchon/ArduinoJson@^7.0.4"

# Or add to platformio.ini:
lib_deps = 
    bblanchon/ArduinoJson@^7.0.4
    other/library@^1.0.0
```

## OTA Updates (Future)

### Setup OTA:
1. Upload initial firmware via USB
2. Note device IP address
3. Update platformio.ini with device IP
4. Use OTA environment:
```bash
platformio run -e esp32-ota -t upload
```

## CI/CD Integration

### GitHub Actions Example:
```yaml
name: Build ESP32 Firmware

on: [push, pull_request]

jobs:
  build:
    runs-on: ubuntu-latest
    steps:
    - uses: actions/checkout@v3
    - name: Set up Python
      uses: actions/setup-python@v4
    - name: Install PlatformIO
      run: pip install platformio
    - name: Build firmware
      run: |
        cd esp32
        platformio run -e esp32-prod
    - name: Upload firmware
      uses: actions/upload-artifact@v3
      with:
        name: firmware
        path: esp32/.pio/build/esp32-prod/firmware.bin
```

## Troubleshooting

### Port Not Found
```bash
# List available ports
platformio device list

# On macOS, look for:
# /dev/tty.usbserial-*
# /dev/tty.SLAB_USBtoUART
```

### Upload Fails
- Hold BOOT button while uploading starts
- Try slower upload speed in platformio.ini
- Check USB cable (some are charge-only)

### Build Errors
```bash
# Clean and rebuild
platformio run -t clean
platformio run -e esp32-dev

# Update platforms and libraries
platformio update
platformio lib update
```

## Production Deployment

### Best Practices:
1. **Use Production Environment**
   ```bash
   platformio run -e esp32-prod
   ```

2. **Version Your Firmware**
   - Update version in main.cpp
   - Tag git releases

3. **Test OTA Updates**
   - Test on dev devices first
   - Have rollback plan

4. **Monitor Devices**
   - Check device status endpoint
   - Set up alerts for offline devices

5. **Secure Your Tokens**
   - Never commit API tokens
   - Use secure storage
   - Rotate tokens periodically

## Summary

**Arduino IDE**: Good for beginners, quick prototypes
**PlatformIO**: Professional development, production deployment

For your smart filter product, PlatformIO is the right choice because:
- Manages multiple devices/configurations
- Integrates with your CI/CD pipeline
- Supports OTA updates for deployed devices
- Professional debugging capabilities
- Reproducible builds for production

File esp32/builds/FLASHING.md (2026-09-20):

# Flashing a monitor from your browser (no tools to install)

Ready-to-flash images, each a single file written at address `0x0`:

- **`smartfilter-usb-pilot-TEST-v1.12.0.bin`** — bench-test build. Needs no
  sensor: a bare dev board sends simulated blower cycles (≈38 Pa on /
  ~0 Pa off, 15-minute cycles) to production. Use this to prove the whole
  pipeline the day the boards arrive.
- **`smartfilter-usb-pilot-v1.12.0.bin`** — real build for assembled units
  with the SDP810 wired (I2C on pins 21/22).

## v1.12.0 — batched uploads: 4-6x fewer requests (SHIP THIS ONE)

One HTTPS request per reading (~6/min while the blower ran) was the
dominant serverless-compute cost — the thing that blew through Vercel's
free tier. Readings are still aggregated on the same cadence (10 s
active / 60 s idle — identical data resolution in the cloud); they now
buffer locally and flush together in one POST /sensor/batch per minute,
each carrying ageSeconds so the server reconstructs exact timestamps.
A failed flush KEEPS the buffer (up to 30 readings) and retries next
minute, so brief network blips lose nothing; the send-failure watchdog
still reboots after 5 consecutive failed flushes. First reading after
boot flushes immediately so the dashboard sees the unit online right
away. Server accepts both paths — older firmware keeps working.

## v1.11.0 — oversampled readings: median + spread

Loss-in-weight-feeder trick, adapted: instead of one snapshot per publish,
the monitor now sub-samples the sensor once a second (each sub-read is
itself the sensor's internal 0.5 ms-sampled average since the previous
read — continuous averaging mode was already on) and publishes the
window's MEDIAN as the pressure value. A median can't be dragged by a
single spike or a blower-transition sample, so every stored reading is a
true window statistic. Also publishes `pressureStd` (the window's spread)
— a free turbulence index that scales with airflow, groundwork for the
flow-drop diagnostics. Server accepts both from this version; older
firmware keeps working unchanged.

## v1.10.5 — over-range readings pegged, fault reasons

Field finding: rail rejection (v1.8.0) has a second trigger besides a
dead sensor — a HEALTHY 125 Pa part whose blower-on dP exceeds ~136 Pa
rails every reading, blacking out entire cycles in a way that mimics a
wiring fault (instant mute at blower start, hands-free recovery at
blower stop). Now: a CRC-valid rail with sane temperature publishes as
a PEGGED 136.5 Pa reading (chart shows a flat ceiling instead of
silence); rails with nonsense temperature still reject (dead sensor).
Fault heartbeats carry the reason: error-nack / error-crc / error-temp.
If a unit pegs, the cure is the SDP810-500Pa part (auto-detected) or
tap relocation.

## v1.10.4 — sensor faults are visible + self-healing

Field lesson: a mute sensor (loose jumper wire) froze BOTH readings and
last-seen — indistinguishable from a dead device, and it mimicked the
BLE bugs all day. Now, after 3 invalid reads the monitor:
- heartbeats the server every 60 s with status "error" (dashboard shows
  ONLINE + sensor fault instead of fake offline)
- blinks the onboard blue LED fast (~5 Hz) — no glow LED required
- re-initializes the sensor every 30 s, which self-heals flaky
  connections, and reports "active" the moment reads recover
Root fix for the pilot unit remains physical: soldered loom / glued
connectors per the build sheet.

## v1.10.3 — presence parked, hardware watchdog added

v1.10.2 still froze solid after ~30-40 min in the field — a hang, not
failed sends, so the software watchdog never ran. Two decisions:
- BLE presence is COMPILED OUT until it's bench-debugged over serial
  (the code remains, off by default). Data reliability beats the glow
  trick. Flash back to 80% of the OTA slot.
- The chip's hardware task watchdog now guards the main loop (300 s):
  any freeze — radio deadlock, heap exhaustion, driver bug — reboots
  the unit automatically. Combined with the send-failure watchdog and
  OTA boot validation, silent death is no longer a reachable state.

## v1.10.2 — duty-cycled BLE + self-healing watchdog

v1.10.1's continuous scan still degraded the network over ~40 min in the
field (heap fragmentation starving TLS). Two structural fixes:
- BLE now scans in 3 s bursts every 30 s (same walk-up latency, ~10% of
  the radio/heap pressure), with a low-heap guard that skips bursts.
- Watchdog: 5 consecutive failed uploads → self-reboot into the
  known-good boot path (WiFi → OTA check → BLE). The monitor can never
  silently stop reporting for more than ~10 minutes, whatever the cause.

## v1.10.1 — fix: BLE scan memory leak (URGENT over v1.10.0)

v1.10.0's continuous BLE scan stored every advertisement it heard; the
results list grew until the heap was exhausted and the TLS connection to
the API died — readings silently stopped within minutes to hours. Fixed
with setMaxResults(0) (callback-only scanning, nothing stored). Do not
ship v1.10.0.

## v1.10.0 — presence-aware glow (BLE proximity)

The monitor now listens passively for Bluetooth signals from phones and
wearables. When someone carrying a device comes within a few meters, the
status glow swells to full brightness and holds for 10 minutes; with
nobody around it settles to a faint 15% idle glow — no more bright LED
lighting up a dark basement all night, and the light "greets" whoever
walks up to check it. Setup mode, connecting, and error states always
show at full brightness. Detection needs a phone/watch on the person;
firmware-only (uses the BLE radio already in the chip). Rev B will add a
$3 mmWave radar for true any-person detection through the enclosure.
Note: the app image is now 93.5% of the OTA slot — spec bigger flash on
Rev B.

## v1.9.0 — survives power outages (field finding)

The first real outage taught us the failure mode: the monitor boots back
in seconds, the router takes minutes, so the ~65 s join attempt fails and
the unit sat in setup mode FOREVER (broadcasting SmartFilter_Setup, no
data). Now a configured unit in setup mode reboots and retries the join
every 5 minutes, indefinitely, until it reconnects — unless someone is
actively using the setup portal (any page touch or AP association resets
the 5-minute clock, so reconfiguring is never interrupted). Also enables
WiFi auto-reconnect for transient drops during normal operation. Interim
recovery for a v1.8.0 unit stuck in setup mode: power-cycle it once the
router is back.

Both include the captive-portal WiFi setup and the device-secret handshake.

## Steps (Chrome or Edge on a computer — phones can't do this part)

1. Plug the board into the computer with a **data** USB cable (some charge-
   only cables won't work — if no port shows up in step 3, try another cable).
2. Open **https://espressif.github.io/esptool-js/** (Espressif's official
   web flasher).
3. Under Program: Baudrate 460800 → click **Connect** → pick the port
   (usually "CP2102 USB to UART" or "USB Serial").
4. Flash Address: **0x0** · File: choose the `.bin` → click **Program**.
5. Wait for "Leaving... Hard resetting" (~1 min), then unplug/replug the
   board.

## After flashing — the customer setup flow

1. The board broadcasts WiFi network **SmartFilter_Setup** — join it from
   your phone.
2. The setup page pops up (if not, open any web page); pick your home WiFi
   and enter its password.
3. It redirects to mysmartfilter.com/setup/device to link the monitor to
   your account.
4. Within a minute or two the device shows readings on the dashboard, and
   in the Admin fleet dashboard.

Factory reset (wipe WiFi + relink): reflash, or hold the board's BOOT
button while tapping EN, then reflash.

## v1.8.0 — stable IDs + TLS validation

- The device ID is now derived from the chip's factory MAC (`SF` + 12 hex),
  so it never changes across setups/wipes. The setup page shows it — that's
  the ID to print on the unit's QR label (**Admin → QR Labels**).
- All API and OTA traffic now validates TLS against pinned root CAs
  (Let's Encrypt + Google Trust Services) with NTP clock sync — a spoofed
  network can no longer impersonate the server or feed fake updates.

## v1.8.0 — sensor auto-zero

Drift correction learned from blower-off periods: when readings sit flat
near zero for ~10 minutes (blower off), that plateau becomes the new zero.
Makes low-cost differential sensors (XGZP-class, ~$2–3) viable for Rev B —
their offset drift self-corrects many times a day.

## v1.8.0 — field-safe OTA

- Devices check for updates on boot AND every 24 h (always-on units never
  reboot, so the daily check is what actually delivers updates).
- Anti-brick: OTA writes to the inactive flash partition (a failed download
  can't touch the running firmware), and on first boot after an update the
  new image must reach the API within ~1 min or it ROLLS ITSELF BACK to the
  previous version. Publishing happens in Admin → Firmware (1% canary →
  ramp → 100%), and only the OTA *application* updates — the bootloader is
  never touched, and browser reflash over USB always remains the fallback.

## v1.8.0 — glow-top status light (button removed)

- RGB LED (common cathode) on GPIO25/26/27 through 220 Ω each, diffused
  through the lid's thin glow window. Colors: pulsing blue = setup mode,
  amber blink = connecting, soft green = filter healthy, solid amber =
  replace soon, breathing red = replace now, fast red blink = can't reach
  the server.
- No button: pairing self-triggers when WiFi is unreachable; account
  transfer = remove the device in the app (it re-registers unclaimed);
  new filters are detected automatically from the pressure drop.
- Reversed pressure tubes (large negative readings) auto-fold positive.
- Wiring diagram: hardware/wiring-usb.svg

## v1.8.0 — reliable WiFi setup handoff (bench-test findings)

Root-caused from the first real bench test:
- The old flow tried to join home WiFi WHILE hosting the setup AP under a
  10 s deadline (routinely too short in mixed mode), dropped the phone
  mid-request (spinner timeout), and WIPED the saved credentials on
  timeout. All three fixed:
- The phone now gets an instant success page (with the Device ID and
  plain next-steps — no doomed auto-redirect), THEN the device reboots
  and joins cleanly with the AP down: two patient 30 s rounds, and
  credentials are never wiped — a failed join returns to setup mode with
  everything kept.
- Boot log now prints the firmware version.

## v1.8.0 — first successful end-to-end bench test

Verified 2026-08-15 on a real unit: captive portal → credentials saved →
joined home WiFi → registered → authenticated → live SDP810 readings
accepted by production (-0.02 Pa with hoses open, 23.9 °C).

Fixes, all of which blocked setup or corrupted data:

- **Setup could never complete on any unit.** `isConfigured()` compared the
  stored config magic against `"SF01"` while every writer stored `"SF02"`,
  so a saved configuration was never recognized — every reboot returned to
  setup mode regardless of network conditions.
- **Every authenticated call returned 401.** The server issues a 67-char
  token (`sf_` + 64 hex) but the buffer held 64, silently truncating it.
- **The setup page hung forever on "Connecting".** The portal ran a WiFi
  scan while hosting the setup AP; the scan takes the radio off-channel and
  wedges the AP data path (clients still associate and get DHCP, but TCP
  dies). The scan now runs once before the AP starts and is served cached.
- **Pressure readings were 4× too high.** The scale factor was hardcoded to
  60 (the 500Pa part) against 125Pa hardware (240). The sensor's own
  reported scale factor is now used, so either variant reads correctly.
- **Sensor faults were published as real data.** A saturated -32768 reading
  passed through the reversed-tube sign fold and became a plausible
  +136.5 Pa. Rail values are now rejected as invalid.
- Sensor init sends stop-continuous first (continuous mode survives a
  reboot, so the start command was being NACKed), and uses 0x3615
  (differential-pressure compensation) rather than 0x3603 (mass flow).
- Measurement CRCs are now validated instead of discarded.

### iPhone setup notes (worth putting in the customer guide)

- iOS routes over cellular when the setup network has no internet, so the
  page won't load. Airplane Mode (with WiFi back on) forces it back.
- After a failed attempt iOS caches "no portal here" and stops probing, so
  the page stops auto-popping. Forget This Network, then rejoin.

### Bench tip

A dead sensor looks like a firmware bug. If pressure reads exactly
±136.53 Pa (raw ±32768) or the temperature is far from room temperature,
suspect the sensor itself — swapping ours fixed it outright.

## v1.8.0 — one-tap setup handoff, adaptive sampling

- The setup success page now shows a "Finish setup" button whose link
  carries the Device ID — nothing to remember or screenshot. Wait for
  SmartFilter_Setup to disappear (phone auto-rejoins home WiFi), tap, done.
- Adaptive sampling: every 10 s while the blower runs (crisp cycle edges
  on the graph), every 60 s while idle.

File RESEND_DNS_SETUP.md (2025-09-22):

# Resend DNS Setup for mysmartfilter.com (Squarespace)

## Required DNS Records

You need to add these DNS records in your Squarespace domain settings to verify your domain with Resend and enable email sending.

### Steps to Add DNS Records in Squarespace:

1. **Log in to Squarespace**
   - Go to your Squarespace account
   - Navigate to Settings → Domains → mysmartfilter.com
   - Click on "DNS Settings" or "Advanced Settings"

2. **Get Your DNS Records from Resend**
   - Go to https://resend.com/domains
   - Click on "Add Domain" if you haven't already
   - Enter: `mysmartfilter.com`
   - Resend will show you 3 records you need to add:

### The 3 DNS Records You Need:

#### 1. SPF Record (TXT)
- **Type:** TXT
- **Host/Name:** @ (or leave blank for root domain)
- **Value:** `v=spf1 include:_spf.resend.com ~all`
- **TTL:** 3600 (or default)

#### 2. DKIM Record (TXT)
- **Type:** TXT  
- **Host/Name:** `resend._domainkey`
- **Value:** (This will be a long string starting with `v=DKIM1; k=rsa; p=...` - copy from Resend dashboard)
- **TTL:** 3600 (or default)

#### 3. Return-Path Record (CNAME)
- **Type:** CNAME
- **Host/Name:** `resend`
- **Value:** `feedback-smtp.resend.com`
- **TTL:** 3600 (or default)

### Adding Records in Squarespace:

1. In Squarespace DNS settings, click "Add Record" for each record
2. Select the appropriate record type (TXT or CNAME)
3. Enter the host/name and value exactly as shown
4. Save each record

### Important Notes for Squarespace:

- **For TXT records**: Squarespace might automatically add quotes around the value - this is normal
- **For the @ symbol**: In Squarespace, use @ or leave the host field blank for the root domain
- **DKIM Host**: Enter exactly `resend._domainkey` (including the dot)
- **Propagation**: DNS changes can take 24-48 hours to fully propagate, but usually work within 1-4 hours

### Verify in Resend:

After adding all records:
1. Go back to https://resend.com/domains
2. Click "Verify DNS Records" for your domain
3. If verification fails, wait 30 minutes and try again (DNS propagation)

### Troubleshooting:

If verification still fails after a few hours:
- Double-check there are no extra spaces in the DNS values
- Ensure the DKIM record was copied completely (it's very long)
- Check if Squarespace added quotes automatically (this is fine)
- Try removing and re-adding the records

### Alternative for Testing:

While waiting for DNS propagation, you can temporarily use:
```
EMAIL_FROM="onboarding@resend.dev"
```
This is Resend's test domain that works immediately without DNS setup.

## Current Status:
- ❌ SPF Failed - Add the SPF TXT record
- ❌ DKIM Failed - Add the DKIM TXT record
- Domain: mysmartfilter.com
- Email: noreply@mysmartfilter.com

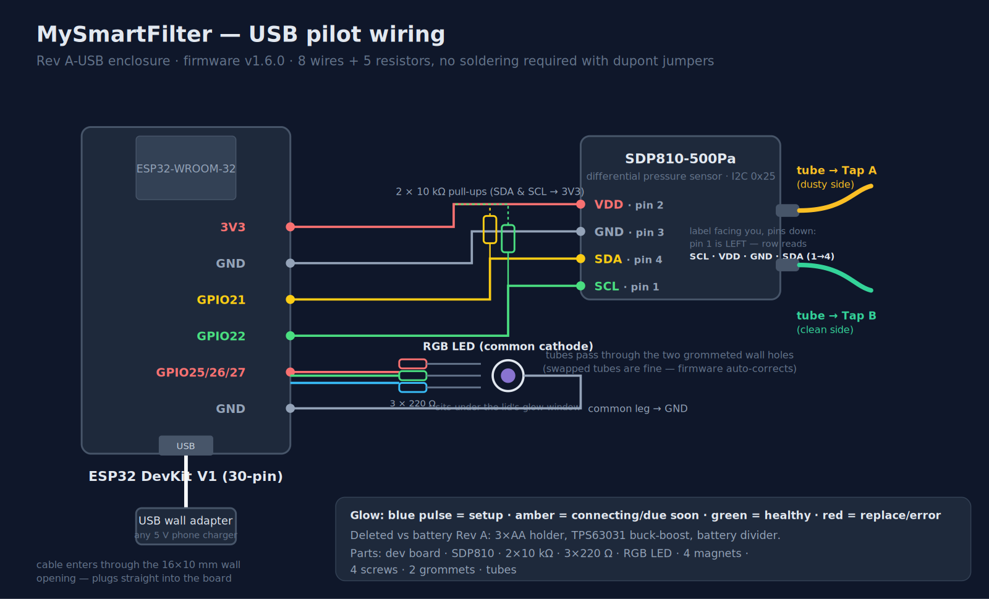
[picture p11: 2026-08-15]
hardware/wiring-usb.png

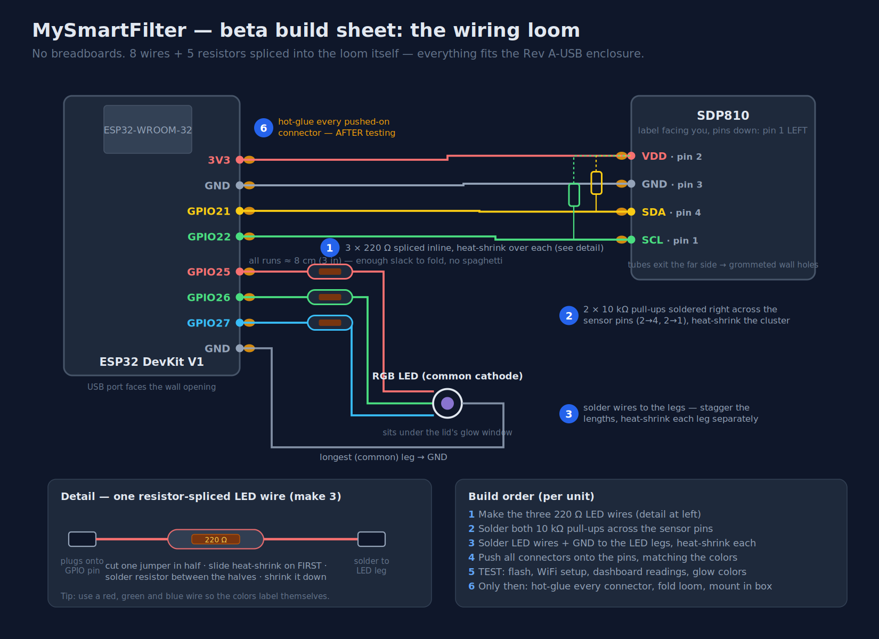
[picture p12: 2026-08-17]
hardware/assembly-loom.png

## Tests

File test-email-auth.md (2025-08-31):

# Email Authentication Testing Guide

## Current Status ✅
- Authentication configuration is set up for both Resend and credentials
- Database is connected and working
- App builds and runs successfully
- Temporary credentials authentication is working for testing

## To Enable Email Authentication:

### 1. Get Resend API Key
1. Go to [resend.com](https://resend.com)
2. Create an account
3. Go to API Keys section
4. Create a new API key
5. Copy the key (starts with `re_`)

### 2. Update Environment Variables
Update your `.env` file:
```bash
RESEND_API_KEY="re_your_actual_key_here"
EMAIL_FROM="noreply@mysmartfilter.com"  # or your verified domain
```

### 3. Test Email Authentication
1. Restart the dev server: `npm run dev`
2. Go to `http://localhost:3000`
3. Click "Get Started Free"
4. You should now see an email input field
5. Enter your email and click "Send magic link"
6. Check your email for the magic link
7. Click the link to sign in

## Current Testing (Without Resend)
Right now you can test with the credentials provider:
1. Go to `http://localhost:3000/api/auth/signin`
2. Choose "Email (Testing)"
3. Enter any email address
4. You'll be signed in immediately (no email sent)

## Production Checklist
- [ ] Get Resend API key
- [ ] Add your domain to Resend
- [ ] Verify your domain in Resend
- [ ] Update EMAIL_FROM to use your verified domain
- [ ] Test email sending in production
- [ ] Remove credentials provider (for security)

## Next Steps After Email is Working
- Commit your beautiful new landing page
- Deploy to Vercel
- Test ESP32 integration
- Set up monitoring alerts

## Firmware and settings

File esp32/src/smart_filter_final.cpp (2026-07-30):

/**
 * Smart Filter Final Production Version
 * - WiFi connection with persistent configuration
 * - Server registration and authentication
 * - Sensor data transmission every 30 seconds
 */

#include <Arduino.h>
#include <WiFi.h>
#include <WebServer.h>
#include <DNSServer.h>
#include <HTTPClient.h>
#include <ArduinoJson.h>
#include <EEPROM.h>

#define LED_PIN 2
#define BUTTON_PIN 0
#define EEPROM_SIZE 512

// Server configuration
const char* SERVER_URL = "http://10.0.0.21:3000/api";

// Configuration structure
struct Config {
  char magic[5];      // "WIFI" + null
  char ssid[33];
  char password[64];
  char deviceId[17];  // Device unique ID
  char apiToken[68];  // API authentication token (sf_ + 64 hex chars + null)
  // Proof-of-possession secret: generated once on this device, sent with every
  // /device/register call so only THIS device can re-fetch its API token.
  // New field at the end of the struct — old EEPROM images leave garbage here,
  // which fails validation and triggers regeneration.
  char deviceSecret[65]; // 64 hex chars + null
};

Config config;
WebServer server(80);
DNSServer dnsServer;
const byte DNS_PORT = 53;

// Timing variables
unsigned long lastDataSend = 0;
unsigned long lastStatusUpdate = 0;
const unsigned long DATA_SEND_INTERVAL = 30000;  // 30 seconds
const unsigned long STATUS_UPDATE_INTERVAL = 300000;  // 5 minutes

// Forward declarations
void startAPMode();
void handleRoot();
void handleSave();
bool connectToWiFi();
void loadConfig();
void saveConfig();
bool isConfigured();
void factoryReset();
void generateDeviceId();
void ensureDeviceSecret();
bool registerDevice();
bool sendSensorData();
bool updateDeviceStatus();

// Simple HTML page for WiFi setup
const char* setupHTML = R"(
<!DOCTYPE html>
<html>
<head>
  <meta name="viewport" content="width=device-width, initial-scale=1">
  <title>Smart Filter Setup</title>
  <style>
    body { font-family: Arial; margin: 20px; background: #f0f0f0; }
    .container { max-width: 400px; margin: 0 auto; background: white; padding: 20px; border-radius: 10px; }
    h2 { color: #333; }
    input { width: 100%; padding: 10px; margin: 10px 0; border: 1px solid #ddd; border-radius: 5px; box-sizing: border-box; }
    button { width: 100%; padding: 15px; background: #4CAF50; color: white; border: none; border-radius: 5px; cursor: pointer; font-size: 16px; }
    button:hover { background: #45a049; }
    .info { background: #e3f2fd; padding: 10px; border-radius: 5px; margin: 10px 0; }
  </style>
</head>
<body>
  <div class="container">
    <h2>🔧 Smart Filter Setup</h2>
    <div class="info">
      <strong>Device ID:</strong> <span style="font-family: monospace;">%DEVICE_ID%</span>
    </div>
    <form action="/save" method="POST">
      <label>WiFi Network (SSID):</label>
      <input type="text" name="ssid" required placeholder="Your WiFi network name">
      <label>WiFi Password:</label>
      <input type="password" name="password" required placeholder="Your WiFi password">
      <button type="submit">Save & Connect</button>
    </form>
    <p style="color: #666; font-size: 14px; margin-top: 20px;">
      After connecting, visit <a href="http://10.0.0.21:3000/devices">http://10.0.0.21:3000/devices</a> 
      to link this device to your account.
    </p>
  </div>
</body>
</html>
)";

void setup() {
  Serial.begin(115200);
  delay(2000);
  
  Serial.println("\n\n========================================");
  Serial.println("Smart Filter - Production Version");
  Serial.println("========================================");
  
  pinMode(LED_PIN, OUTPUT);
  pinMode(BUTTON_PIN, INPUT_PULLUP);
  
  // Initialize EEPROM
  EEPROM.begin(EEPROM_SIZE);
  loadConfig();
  
  // Generate device ID if we don't have one
  if (strlen(config.deviceId) == 0) {
    generateDeviceId();
    saveConfig();
  }

  // Generate/repair the proof-of-possession secret if missing or invalid
  ensureDeviceSecret();

  Serial.printf("Device ID: %s\n", config.deviceId);
  
  // Check for factory reset (hold BOOT button for 5 seconds)
  if (digitalRead(BUTTON_PIN) == LOW) {
    Serial.println("BOOT button pressed, hold for 5 seconds to factory reset...");
    unsigned long pressStart = millis();
    while (digitalRead(BUTTON_PIN) == LOW && millis() - pressStart < 5000) {
      digitalWrite(LED_PIN, (millis() / 100) % 2);  // Fast blink
    }
    if (millis() - pressStart >= 5000) {
      factoryReset();
    }
  }
  
  // Try to connect if we have WiFi config
  if (isConfigured()) {
    Serial.printf("Found WiFi config: SSID=%s\n", config.ssid);
    if (connectToWiFi()) {
      Serial.println("✓ Connected to WiFi!");
      Serial.printf("  IP Address: %s\n", WiFi.localIP().toString().c_str());
      Serial.printf("  MAC Address: %s\n", WiFi.macAddress().c_str());
      Serial.printf("  Signal: %d dBm\n", WiFi.RSSI());
      digitalWrite(LED_PIN, HIGH);  // Solid = connected
      
      // Register device if no token
      if (strlen(config.apiToken) == 0) {
        Serial.println("\nNo API token found. Registering device...");
        if (registerDevice()) {
          Serial.println("✓ Device registered successfully!");
        } else {
          Serial.println("⚠ Device registration failed. Will retry later.");
        }
      } else {
        Serial.printf("✓ Using existing API token: %.10s...\n", config.apiToken);
      }
      
      // Update device status
      updateDeviceStatus();
      
      Serial.println("\n✓ Setup complete! Sending data every 30 seconds.");
      return;  // Exit setup, go to loop
    } else {
      Serial.println("✗ Failed to connect to saved WiFi");
    }
  } else {
    Serial.println("No WiFi configuration found");
  }
  
  // Start AP mode for configuration
  Serial.println("Starting setup mode...");
  startAPMode();
}

void loop() {
  if (WiFi.getMode() == WIFI_AP) {
    // Setup mode - handle web server
    dnsServer.processNextRequest();
    server.handleClient();
    
    // Blink LED in setup mode
    digitalWrite(LED_PIN, (millis() / 500) % 2);
    
  } else if (WiFi.status() == WL_CONNECTED) {
    // Connected mode - send data
    
    // Send sensor data every 30 seconds
    if (millis() - lastDataSend >= DATA_SEND_INTERVAL) {
      if (sendSensorData()) {
        Serial.println("✓ Data sent successfully");
        // Quick flash to indicate success
        digitalWrite(LED_PIN, LOW);
        delay(50);
        digitalWrite(LED_PIN, HIGH);
      } else {
        Serial.println("✗ Failed to send data");
      }
      lastDataSend = millis();
    }
    
    // Update device status every 5 minutes
    if (millis() - lastStatusUpdate >= STATUS_UPDATE_INTERVAL) {
      updateDeviceStatus();
      lastStatusUpdate = millis();
    }
    
  } else {
    // Lost connection - try to reconnect
    Serial.println("WiFi disconnected! Attempting to reconnect...");
    digitalWrite(LED_PIN, LOW);
    if (connectToWiFi()) {
      Serial.println("✓ Reconnected to WiFi");
      digitalWrite(LED_PIN, HIGH);
    } else {
      Serial.println("✗ Reconnection failed. Restarting...");
      delay(5000);
      ESP.restart();
    }
  }
  
  // Handle factory reset button
  static unsigned long buttonPressTime = 0;
  if (digitalRead(BUTTON_PIN) == LOW) {
    if (buttonPressTime == 0) {
      buttonPressTime = millis();
    } else if (millis() - buttonPressTime > 5000) {
      factoryReset();
    }
  } else {
    buttonPressTime = 0;
  }
}

void startAPMode() {
  WiFi.mode(WIFI_AP);
  WiFi.softAP("SmartFilter_Setup");
  
  IPAddress IP = WiFi.softAPIP();
  Serial.println("\n========================================");
  Serial.println("Setup Mode Active!");
  Serial.println("========================================");
  Serial.println("1. Connect to WiFi: SmartFilter_Setup");
  Serial.printf("2. Open browser: http://%s\n", IP.toString().c_str());
  Serial.println("3. Enter your WiFi credentials");
  Serial.println("========================================\n");
  
  // Setup DNS to redirect all to our IP
  dnsServer.start(DNS_PORT, "*", IP);
  
  // Setup web server
  server.on("/", handleRoot);
  server.on("/save", HTTP_POST, handleSave);
  server.onNotFound(handleRoot);
  
  server.begin();
}

void handleRoot() {
  String html = String(setupHTML);
  html.replace("%DEVICE_ID%", config.deviceId);
  server.send(200, "text/html", html);
}

void handleSave() {
  String ssid = server.arg("ssid");
  String password = server.arg("password");
  
  Serial.printf("\nReceived config: SSID=%s\n", ssid.c_str());
  
  // Save to config
  strcpy(config.magic, "WIFI");
  ssid.toCharArray(config.ssid, sizeof(config.ssid));
  password.toCharArray(config.password, sizeof(config.password));
  
  // Clear any old token when setting up new WiFi
  memset(config.apiToken, 0, sizeof(config.apiToken));
  
  // Save to EEPROM
  saveConfig();
  
  // Send response
  String html = "<html><body style='font-family: Arial; padding: 20px;'>";
  html += "<h2>✓ Configuration Saved!</h2>";
  html += "<p>Device ID: <strong>" + String(config.deviceId) + "</strong></p>";
  html += "<p>The device will restart and connect to: <strong>" + ssid + "</strong></p>";
  html += "<p>After connecting, visit your dashboard to link this device.</p>";
  html += "</body></html>";
  server.send(200, "text/html", html);
  
  delay(3000);
  ESP.restart();
}

bool connectToWiFi() {
  WiFi.mode(WIFI_STA);
  WiFi.begin(config.ssid, config.password);
  
  Serial.printf("Connecting to %s", config.ssid);
  int attempts = 0;
  while (WiFi.status() != WL_CONNECTED && attempts < 30) {
    delay(500);
    Serial.print(".");
    attempts++;
  }
  Serial.println();
  
  return (WiFi.status() == WL_CONNECTED);
}

void generateDeviceId() {
  const char chars[] = "ABCDEFGHIJKLMNOPQRSTUVWXYZ0123456789";
  
  // Use MAC address for randomness
  uint8_t mac[6];
  WiFi.macAddress(mac);
  randomSeed(mac[5] + (mac[4] << 8) + (mac[3] << 16));
  
  strcpy(config.deviceId, "SF");
  for (int i = 2; i < 16; i++) {
    config.deviceId[i] = chars[random(0, 36)];
  }
  config.deviceId[16] = '\0';
  
  Serial.printf("Generated Device ID: %s\n", config.deviceId);
}

void ensureDeviceSecret() {
  // Valid = exactly 64 lowercase hex chars
  bool valid = strlen(config.deviceSecret) == 64;
  if (valid) {
    for (int i = 0; i < 64; i++) {
      char c = config.deviceSecret[i];
      if (!((c >= '0' && c <= '9') || (c >= 'a' && c <= 'f'))) {
        valid = false;
        break;
      }
    }
  }
  if (valid) return;

  // Generate 32 random bytes from the hardware RNG, hex-encode
  const char hex[] = "0123456789abcdef";
  for (int i = 0; i < 32; i++) {
    uint32_t r = esp_random();
    config.deviceSecret[i * 2] = hex[r & 0x0F];
    config.deviceSecret[i * 2 + 1] = hex[(r >> 4) & 0x0F];
  }
  config.deviceSecret[64] = '\0';
  saveConfig();
  Serial.println("✓ Generated new device secret");
}

bool registerDevice() {
  if (WiFi.status() != WL_CONNECTED) return false;

  HTTPClient http;
  String url = String(SERVER_URL) + "/device/register";

  http.begin(url);
  http.addHeader("Content-Type", "application/json");

  // Create JSON payload
  StaticJsonDocument<384> doc;
  doc["deviceId"] = config.deviceId;
  doc["type"] = "SmartFilter";
  doc["firmware"] = "1.0.0";
  doc["deviceSecret"] = config.deviceSecret;
  
  String jsonString;
  serializeJson(doc, jsonString);
  
  Serial.printf("Registering device: %s\n", config.deviceId);
  Serial.printf("POST %s\n", url.c_str());
  
  int httpCode = http.POST(jsonString);
  
  if (httpCode == 200) {
    String response = http.getString();
    
    // Parse response
    StaticJsonDocument<512> responseDoc;
    DeserializationError error = deserializeJson(responseDoc, response);
    
    if (!error && responseDoc["success"] && responseDoc["token"]) {
      String token = responseDoc["token"].as<String>();
      token.toCharArray(config.apiToken, sizeof(config.apiToken));
      saveConfig();
      Serial.printf("✓ Received token: %.20s...\n", config.apiToken);
      http.end();
      return true;
    }
  } else {
    Serial.printf("✗ Registration failed. HTTP code: %d\n", httpCode);
    if (httpCode > 0) {
      Serial.printf("Response: %s\n", http.getString().c_str());
    }
  }
  
  http.end();
  return false;
}

bool sendSensorData() {
  if (WiFi.status() != WL_CONNECTED) return false;
  
  // Register if we don't have a token
  if (strlen(config.apiToken) == 0) {
    Serial.println("No token, attempting registration...");
    if (!registerDevice()) {
      return false;
    }
  }
  
  HTTPClient http;
  String url = String(SERVER_URL) + "/sensor";
  
  http.begin(url);
  http.addHeader("Content-Type", "application/json");
  http.addHeader("Authorization", "Bearer " + String(config.apiToken));
  
  // Generate test sensor data (replace with real sensor later)
  float pressure = 10.0 + (random(-50, 50) / 10.0);
  float temperature = 22.0 + (random(-30, 30) / 10.0);
  
  StaticJsonDocument<128> doc;
  doc["pressure"] = pressure;
  doc["temperature"] = temperature;
  
  String jsonString;
  serializeJson(doc, jsonString);
  
  Serial.printf("[%lu s] Sending: P=%.1f Pa, T=%.1f°C", 
                millis()/1000, pressure, temperature);
  
  int httpCode = http.POST(jsonString);
  bool success = (httpCode == 200);
  
  if (success) {
    Serial.println(" ✓");
  } else {
    Serial.printf(" ✗ (HTTP %d)\n", httpCode);
    
    // If unauthorized, clear token to force re-registration
    if (httpCode == 401) {
      Serial.println("Token invalid, clearing for re-registration");
      memset(config.apiToken, 0, sizeof(config.apiToken));
      saveConfig();
    }
  }
  
  http.end();
  return success;
}

bool updateDeviceStatus() {
  if (WiFi.status() != WL_CONNECTED || strlen(config.apiToken) == 0) return false;
  
  HTTPClient http;
  String url = String(SERVER_URL) + "/device/status";
  
  http.begin(url);
  http.addHeader("Content-Type", "application/json");
  http.addHeader("Authorization", "Bearer " + String(config.apiToken));
  
  StaticJsonDocument<256> doc;
  doc["status"] = "active";
  doc["firmware"] = "1.0.0";
  doc["rssi"] = WiFi.RSSI();
  doc["ip"] = WiFi.localIP().toString();
  doc["uptime"] = millis() / 1000;
  
  String jsonString;
  serializeJson(doc, jsonString);
  
  int httpCode = http.PUT(jsonString);
  
  if (httpCode == 200) {
    Serial.println("✓ Status updated");
  } else {
    Serial.printf("✗ Status update failed (HTTP %d)\n", httpCode);
  }
  
  http.end();
  return (httpCode == 200);
}

void loadConfig() {
  EEPROM.get(0, config);
  if (strcmp(config.magic, "WIFI") != 0) {
    Serial.println("No valid config in EEPROM");
    memset(&config, 0, sizeof(config));
  }
}

void saveConfig() {
  EEPROM.put(0, config);
  if (EEPROM.commit()) {
    Serial.println("✓ Configuration saved");
  } else {
    Serial.println("✗ Failed to save configuration!");
  }
}

bool isConfigured() {
  return strcmp(config.magic, "WIFI") == 0 && strlen(config.ssid) > 0;
}

void factoryReset() {
  Serial.println("\n!!! FACTORY RESET !!!");
  
  // Flash LED rapidly
  for(int i = 0; i < 20; i++) {
    digitalWrite(LED_PIN, i % 2);
    delay(50);
  }
  
  // Clear configuration
  memset(&config, 0, sizeof(config));
  EEPROM.put(0, config);
  EEPROM.commit();
  
  Serial.println("Configuration cleared!");
  delay(1000);
  ESP.restart();
}

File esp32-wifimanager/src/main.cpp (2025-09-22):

#include <WiFi.h>
#include <WebServer.h>
#include <DNSServer.h>
#include <HTTPClient.h>
#include <ArduinoJson.h>
#include <EEPROM.h>
#include <Wire.h>

// EEPROM storage structure
struct Config {
  char magic[4];  // "SF01" to verify valid config
  char ssid[33];
  char password[64];
  char deviceId[17];  // 16 chars + null terminator
  char apiToken[65];  // 64 chars + null terminator
  bool configured;
};

// Configuration constants
const char* AP_SSID = "SmartFilter_Setup";
const char* AP_PASSWORD = "";  // Open network for easy access
const char* API_BASE_URL = "https://mysmartfilter.com/api";
const byte DNS_PORT = 53;
const int CONFIG_VERSION = 1;

// Hardware configuration
#define SDP810_I2C_ADDRESS 0x25
#define LED_PIN 2  // Built-in LED for status

// Global objects
WebServer server(80);
DNSServer dnsServer;
Config config;
bool wifiConnected = false;
unsigned long lastReading = 0;
const unsigned long readingInterval = 30000;  // 30 seconds

// Sensor data structure
struct SensorData {
  float pressure;
  float temperature;
  bool valid;
};

// HTML for captive portal
const char SETUP_HTML[] PROGMEM = R"rawliteral(
<!DOCTYPE html>
<html>
<head>
    <meta name="viewport" content="width=device-width, initial-scale=1">
    <title>Smart Filter Setup</title>
    <style>
        body {
            font-family: -apple-system, BlinkMacSystemFont, "Segoe UI", Roboto, sans-serif;
            margin: 0;
            padding: 20px;
            background: linear-gradient(135deg, #667eea 0%, #764ba2 100%);
            min-height: 100vh;
        }
        .container {
            max-width: 400px;
            margin: 0 auto;
            background: white;
            padding: 30px;
            border-radius: 20px;
            box-shadow: 0 20px 60px rgba(0,0,0,0.3);
        }
        h1 {
            color: #333;
            margin: 0 0 10px 0;
            font-size: 28px;
        }
        .subtitle {
            color: #666;
            margin-bottom: 30px;
            font-size: 14px;
        }
        .status {
            background: #f0f9ff;
            border-left: 4px solid #3b82f6;
            padding: 12px;
            margin-bottom: 20px;
            border-radius: 4px;
        }
        input[type="text"], input[type="password"] {
            width: 100%;
            padding: 12px;
            margin: 8px 0;
            border: 2px solid #e5e7eb;
            border-radius: 8px;
            font-size: 16px;
            transition: border-color 0.3s;
            box-sizing: border-box;
        }
        input:focus {
            outline: none;
            border-color: #3b82f6;
        }
        label {
            display: block;
            margin-top: 15px;
            color: #374151;
            font-weight: 500;
            font-size: 14px;
        }
        button {
            width: 100%;
            padding: 14px;
            margin-top: 20px;
            background: linear-gradient(135deg, #667eea 0%, #764ba2 100%);
            color: white;
            border: none;
            border-radius: 8px;
            font-size: 16px;
            font-weight: 600;
            cursor: pointer;
            transition: transform 0.2s;
        }
        button:hover {
            transform: translateY(-2px);
        }
        button:disabled {
            opacity: 0.5;
            cursor: not-allowed;
        }
        .device-id {
            background: #f3f4f6;
            padding: 10px;
            border-radius: 6px;
            font-family: monospace;
            margin: 10px 0;
            word-break: break-all;
        }
        .step {
            background: #fef3c7;
            border: 1px solid #fbbf24;
            padding: 15px;
            border-radius: 8px;
            margin: 20px 0;
        }
        .spinner {
            display: none;
            width: 20px;
            height: 20px;
            border: 3px solid #f3f3f3;
            border-top: 3px solid #667eea;
            border-radius: 50%;
            animation: spin 1s linear infinite;
            margin: 20px auto;
        }
        @keyframes spin {
            0% { transform: rotate(0deg); }
            100% { transform: rotate(360deg); }
        }
        .error {
            color: #ef4444;
            font-size: 14px;
            margin-top: 5px;
        }
        .success {
            color: #10b981;
            font-size: 14px;
            margin-top: 5px;
        }
        #networks {
            margin: 10px 0;
        }
        .network-item {
            padding: 10px;
            margin: 5px 0;
            border: 2px solid #e5e7eb;
            border-radius: 8px;
            cursor: pointer;
            transition: all 0.3s;
        }
        .network-item:hover {
            border-color: #3b82f6;
            background: #f0f9ff;
        }
        .signal-strength {
            float: right;
            color: #666;
        }
    </style>
</head>
<body>
    <div class="container">
        <h1>🔧 Smart Filter Setup</h1>
        <p class="subtitle">Connect your filter monitor to WiFi</p>
        
        <div class="status">
            <strong>Device ID:</strong>
            <div class="device-id" id="deviceId">Generating...</div>
        </div>

        <form id="setupForm">
            <label>WiFi Network</label>
            <div id="networks">
                <div style="text-align: center; padding: 20px;">
                    <div class="spinner" style="display: block;"></div>
                    <p>Scanning for networks...</p>
                </div>
            </div>
            <input type="text" id="ssid" name="ssid" placeholder="Or enter network name manually" required>
            
            <label>WiFi Password</label>
            <input type="password" id="password" name="password" placeholder="Enter WiFi password" required>
            
            <div class="step">
                <strong>Next Step:</strong> After connecting to WiFi, you'll be redirected to mysmartfilter.com to complete setup and link this device to your account.
            </div>
            
            <button type="submit" id="submitBtn">Connect to WiFi</button>
            <div id="message"></div>
        </form>
    </div>

    <script>
        // Generate random device ID on page load
        function generateDeviceId() {
            const chars = 'ABCDEFGHIJKLMNOPQRSTUVWXYZ0123456789';
            let deviceId = 'SF';
            for (let i = 0; i < 14; i++) {
                deviceId += chars.charAt(Math.floor(Math.random() * chars.length));
            }
            return deviceId;
        }

        // Display device ID
        const deviceId = generateDeviceId();
        document.getElementById('deviceId').textContent = deviceId;
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

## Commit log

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2026-01-04 Add filter store with Stripe checkout and auto-order support
    - Add store pages: browse filters, checkout, order history
    - Add Stripe integration for payments
    - Add device filter preferences with auto-order toggle
    - Add ESP32 filter alert endpoint for clogged filter detection
    - Add 27 filter products (various sizes, MERV ratings)
    - Update Next.js to 16.1.1 to fix CVE vulnerability
    - Add device detail page with settings
2026-01-04 Fix: Downgrade to Next.js 15.2.8 for next-auth compatibility
    Next.js 16.x breaks peer dependency with next-auth@5.0.0-beta.25.
    Using patched Next.js 15.2.8 which fixes CVE-2025-55182 and is
    compatible with current next-auth version.
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2026-01-08 Fix production deployment: switch back to PostgreSQL
    - Changed Prisma datasource from sqlite to postgresql
    - Migrated production database with new store models
    - Seeded 27 filter products into production
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2026-03-16 feat: Add Device Wizard + Rename/Delete UI
    Task 1 — /setup/device wizard (replaces QR-code-only flow):
    - Step 1: Power On with animated pulsing blue LED
    - Step 2: Device ID input (SF + 14 alphanum validation), QR Coming Soon
    placeholder, calls POST /api/device/provision
    - Step 3: Name + location inputs, calls PUT /api/device/provision,
    redirects to /devices on success
    - Progress bar with step counter throughout
    Task 2 — device-settings.tsx additions below Filter Settings:
    - Rename Device section: inline name + location fields, PUT /api/device/[id],
    success/error feedback + router.refresh()
    - Danger Zone section: Delete Device button, inline confirmation with
    typed-name gate, DEL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
2026-03-16 feat(setup): upgrade device wizard to 4 steps with QR scanning + captive portal
    - Install @zxing/browser for real camera-based QR code scanning
    - Step 2 (Identify Device): replace disabled stub with live QR scanner
    - Toggle between QR scan (default) and manual entry
    - Camera preview with corner-bracket overlay (no ugly box)
    - Graceful fallback to manual entry if camera permission denied
    - Auto-provision on valid SF[14char] QR scan, skip manual submit
    - Step 3 (Connect to WiFi): new captive portal guidance step
    - Numbered instructions with SmartFilter-XXXXXX WiFi network hint
    - Pulsing green LED animation (matches Step 1 blue pulse style)
    - Background polling every 3s via GET /a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
2026-03-16 feat: wire up Resend emails + device-offline and auto-order crons
    - src/lib/resend.ts: Resend singleton client using RESEND_API_KEY env var
    - src/app/api/device/alert/route.ts: replace TODO stub with real Resend email
    - Dark-styled HTML email with device name, location, pressure vs threshold
    - Auto-order branch: 24h countdown notice with dashboard cancel link
    - Manual-order branch: 'Order Replacement Filter' CTA → /store
    - src/app/api/cron/device-offline/route.ts: Vercel Cron (every 15 min)
    - Finds devices with lastSeen 15–60 min ago, status != 'offline'
    - Sets status to 'offline', sends 'Device offline' email once per transition
    - Secured with CRON_SECRET Bearer token check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
2026-03-16 feat: Alert management UI (P2)
    - Add PATCH /api/device/alert/[alertId] endpoint (dismiss + manual_ordered)
    - Add Dismiss and Mark as Ordered buttons to active alert cards
    - Add Alert History panel (last 10 alerts, color-coded status badges, relative time)
    - Add device.getAlerts tRPC procedure for history panel
    - Add Pressure Threshold (Alert Threshold) input to Device Info settings
    - Update PUT /api/device/[deviceId] to accept pressureThreshold
    - Fix GET/PUT/DELETE handlers to look up device by id (cuid) not deviceId field
    - Add offline amber banner to device cards in device list
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2026-03-28 feat(ota): implement P3 OTA firmware updates
    - Add FirmwareRelease Prisma model (version, binaryUrl, releaseNotes, isActive)
    - Apply schema changes via prisma db push (Neon PostgreSQL)
    - Add /api/ota/check — bearer-auth endpoint for ESP32 to check for updates
    - Add /api/ota/download/[version] — redirects to firmware binary URL
    - Add firmware tRPC router (list, publish, setActive mutations)
    - Register firmware router in root.ts
    - Update captive_portal.cpp: add checkOTAUpdate() using HTTPUpdate + WiFiClientSecure
    - Call checkOTAUpdate() from startNormalOperation() after WiFi + registration
    - Add FIRMWARE_VERSION build flag to captive-portal-dev and captive-portal-prod envs
    - Replace hardco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
    [captive_portal.cpp]
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2026-07-30 feat: Phase 3 launch surface + firmware device-secret
    - Landing page: hero rewritten around the energy-cost value prop; footer
    now has real links (terms/privacy/store/setup) instead of dead anchors
    and a non-functional subscribe form; metadata + titles updated
    - Legal: /terms and /privacy pages (drafts for founder review)
    - Rate limiting (in-memory fixed-window) on /api/sensor,
    /api/device/register, /api/v1/devices, /api/alert/cancel
    - Security: stop logging device API tokens in the sensor route
    - PWA: manifest + generated app icons; installable dashboard
    - Welcome email on account creation (NextAuth createUser event)
    - Lazy Resend client — builds without RESEND_API_KEY no longer cra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
    [smart_filter_final.cpp]
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2026-08-02 feat(firmware): Rev B battery firmware — deep-sleep batch architecture
    smart_filter_battery.cpp: wake every 2 min, triggered SDP810 read with
    sensor rail powered only ~75 ms, samples buffered in RTC memory (90-cap
    ring), hourly batch upload to /api/sensor/batch with ageSeconds offsets,
    exception-push on blower edges / alert crossings / battery <20%, WiFi
    fast-reconnect via cached channel+BSSID, self-healing re-register with
    the device secret on 401, captive portal + factory reset carried over.
    New pio envs: esp32-battery (prod) and esp32-battery-dev (fake sensor).
    Compile verification in progress — fixes follow if the toolchain flags
    anything.
    [smart_filter_battery.cpp]
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2026-08-05 feat(tiers): enforce Filter AutoShip gating + button-press health LED
    Enforcement (server-side first, UI second):
    - sensor.getByTimeRange clamps free accounts to a 1-hour live window
    regardless of what the client requests; new sensor.getMembership query
    - CSV export returns 403 with an upsell message for free accounts
    - Device page: Filter Health card renders a locked AutoShip upsell state
    for free tier; chart ranges beyond 1h disabled with lock hints; Export
    button hidden
    - v1 API: plan field ("autoship"/"free"); energy-model outputs nulled on
    free so smart-home integrations respect tiers (HA degrades gracefully)
    Health LED (StuckAtPrototype-inspired glanceable feedback):
    - /api/se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
    [smart_filter_battery.cpp]
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2026-08-10 USB-pilot firmware: device-secret handshake + browser-flashable builds (#20)
    captive_portal.cpp gains the deviceSecret handshake (hardware-RNG secret
    in EEPROM, presented on /api/device/register — config layout bumped to
    SF02), SKIP_SENSOR simulated readings for bare-board bench tests, and
    explicit forward declarations. New usb-pilot-prod / usb-pilot-fake envs;
    both compile clean. Merged single-file images + browser flashing guide in
    esp32/builds/.
    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
    [captive_portal.cpp]
2026-08-10 Accuracy, ops, and pilot hardening: rates, health, QR labels, firmware v1.2.0 (#21)
    Web:
    - State-average electricity-rate suggestion in the HVAC card (EIA-based
    table, one-click apply; utility-bill number always wins)
    - GET /api/health for external uptime monitoring (DB reachability, terse)
    - /admin/labels: printable per-device QR sheet (registered devices +
    pasted IDs) encoding the setup URL; linked from the admin dashboard
    Firmware v1.2.0 (both merged images rebuilt):
    - Stable device IDs derived from the chip's factory MAC — QR labels
    printed at flash time stay correct forever; portal fetches the ID from
    the firmware instead of inventing a random one per page load
    - TLS validati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
    [captive_portal.cpp]
2026-08-11 PSC runtime-penalty energy model + firmware auto-zero v1.3.0 (#22)
    * PSC runtime-penalty energy model + firmware sensor auto-zero (v1.3.0)
    Energy model: PSC systems now accrue real waste. A clogged filter on a
    fixed-speed blower doesn't raise blower draw — it cuts airflow, which cuts
    delivered capacity, so the whole system (compressor included) runs longer
    to satisfy the thermostat. Modeled conservatively (0.2%/Pa airflow loss,
    capacity ~ sqrt(airflow), ~1.1 kW/ton system power) and documented in
    src/lib/energy.ts. Cost-vs-price alerts and the Filter Health meter now
    apply to both blower types, with the pressure threshold kept as a parallel
    ceiling. Physics sanity-checked (ECM reference u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
    [captive_portal.cpp]
2026-08-11 Field-safe OTA: rollback, daily checks, staged rollout, admin releases (#23)
    Firmware v1.4.0:
    - validateOtaBoot(): first boot after an OTA must reach the API over
    pinned TLS within 3 attempts or the image rolls itself back to the
    previous partition (Update.rollBack) — the anti-brick guarantee
    - otaPending flag appended to config (SF02-compatible; only ==1 is armed)
    - Daily OTA re-check in loop() — always-on units never reboot, so the
    boot-only check would never fire in the field
    Server:
    - FirmwareRelease.rolloutPct + deterministic deviceId-hash bucketing in
    /api/ota/check — staged rollouts (1% canary default) that only ever add
    devices as the percentage ramps
    - /admin/firmwa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
    [captive_portal.cpp]
2026-08-13 USB wiring diagram + firmware v1.5.0: lid button/LED, reversed-tube tolerance (#24)
    - hardware/wiring-usb.svg/png: current wiring for the USB pilot — ESP32
    DevKit V1, SDP810 on I2C 21/22 with 2x10k pull-ups, lid LED on GPIO26
    (220R), lid button on GPIO27 (INPUT_PULLUP), USB power through the wall
    opening; replaces the obsolete battery Rev A diagram
    - Firmware v1.5.0: lid button (short press = status blink 3 slow/6 fast,
    10 s hold = factory reset), external lid LED mirrors status, reversed
    pressure tubes fold positive (honors the install guide's 'either tube'
    promise). OTA image staged at public/firmware/smartfilter-1.5.0-usb.bin.
    Claude-Session: https://claude.ai/code/session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
    [captive_portal.cpp]
2026-08-14 Glow-top status light + automatic new-filter detection, fw v1.6.0 (#25)
    - src/lib/filter-replacement.ts: auto-detects a fresh filter — blower-on
    deltaP falling back to within 4 Pa of the clean baseline for 3
    consecutive readings, after the filter was demonstrably loaded (>=15 Pa
    rise or >=10 cents accrued) — then resets tracking, resolves open
    alerts, and emails the customer. Wired into both ingest paths.
    - /api/sensor response now returns filterStatus so always-on devices can
    display the verdict.
    Firmware v1.6.0 (button removed by founder decision):
    - Glow-top RGB LED on GPIO25/26/27 (PWM): pulsing blue = setup, amber
    blink = connecting, soft green = healthy, solid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
    [enclosure-usb.step, lid-usb.stl]
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2026-08-15 fw v1.7.0: reliable WiFi setup handoff, first-bench-test findings (#27)
    Root cause of the field-observed 'spinner timeout' + lost credentials:
    handleConfigure joined the home network WHILE hosting the setup AP under
    a 10 s deadline (routinely too short in AP+STA mode), which dropped the
    phone mid-request, and the timeout path called clearConfig() — wiping
    the just-entered credentials.
    Fixes:
    - Respond to the phone immediately (success page shows the Device ID and
    plain next-steps; no auto-redirect into a no-internet network), THEN
    reboot and join cleanly with the AP down
    - Boot-time join: two patient 30 s rounds with a disconnect/retry between
    - Credentials are never wiped — a faile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
    [captive_portal.cpp]
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2026-08-15 fw 1.7.1-usb-dev: cache WiFi scan pre-AP + trace portal requests
    Bench diagnosis of the endless setup spinner: serial tracing showed the
    portal page loads, then the board goes deaf — the POST /configure never
    arrives, while the AP keeps beaconing (phone still shows "connected").
    Prime suspect: handleScan() ran WiFi.scanNetworks() synchronously while
    hosting the soft-AP; the scan flips the radio to STA and goes off-channel,
    wedging the AP data path (DHCP/TCP) for connected clients. The page's JS
    fires /scan 1 s after load — exactly our failure window, on every attempt.
    - Scan once in startSetupMode() BEFORE the AP starts (no clients = safe),
    serve cached results from /scan; never scan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
    [captive_portal.cpp]
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2026-08-15 fw 1.7.3-usb-dev: fix config persistence — setup could never complete
    Bench test got the whole portal flow working (page served, POST /configure
    received, "Config saved"), but the reboot came up "No configuration found"
    and returned to setup mode. Two pre-existing bugs, both in main:
    1. isConfigured() compared magic against "SF01" while every writer stores
    "SF02" (stale from the SF01->SF02 migration). It returns false forever,
    so a saved config is never recognized — no device could EVER finish
    setup on this firmware, regardless of network conditions.
    2. char magic[4] cannot hold "SF02" plus its NUL: strcpy overflowed one
    byte into ssid[0] and strcmp read past the array. Wide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
    [captive_portal.cpp]
2026-08-15 fw 1.7.4-usb-dev: fix 401s (token truncation) + SF03 config migration
    Bench test reached production: device joined WiFi, synced clock, read the
    SDP810, and registered successfully — but every authenticated call after
    that returned 401 and no reading was accepted.
    1. Token truncation. The server issues `sf_` + 64 hex = 67 chars, but
    apiToken was char[65], so toCharArray() silently dropped the last 3
    characters and every authenticated request failed. Widened to char[80].
    2. Config migration. Widening magic[4]->magic[5] in 1.7.3 was not enough:
    the OLD overflowing strcpy had written "SF02" + NUL across 5 bytes, so
    a stale SF02 blob still validates against the new 5-byte magic wh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
    [captive_portal.cpp]
2026-08-15 fw 1.7.5-usb-dev: validate SDP810 CRC, fix scale factor and byte order
    Bench readings were implausible: 546 Pa with both hoses open (true ~0) and
    46 C in a 22 C room. Temperature uses the correct /200 divisor for every
    SDP8xx variant, so a second, non-arithmetic fault is present — most likely
    corrupted I2C reads.
    - Validate the CRC-8 (poly 0x31, init 0xFF) that follows each word instead
    of reading and discarding it. Corrupted frames are now rejected and the
    raw bytes logged, which distinguishes a marginal bus (missing/weak
    SDA/SCL pull-up) from a data-interpretation bug.
    - Scale factor: firmware hardcoded 60 Pa-1 (the 500Pa part) while the
    hardware is SDP810-125Pa, which is 240 Pa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
    [captive_portal.cpp]
2026-08-15 fw 1.7.6-usb-dev: fix SDP810 init, reject saturated readings
    Raw frame from the bench (CRC valid, so the I2C bus is fine):
    [sdp] raw dp=-32768 temp=9223 scale=240
    -32768 is the signed-16 rail, i.e. a fault value, not a measurement.
    Root cause: the sensor keeps measuring across an ESP32 reboot (continuous
    mode ends only on command or power loss), so re-sending a start command was
    NACKed ("Failed to initialize SDP810 sensor") and it kept streaming a
    saturated value. Init now sends stop-continuous (0x3FF9) first, making it
    idempotent.
    Also switched the start command from 0x3603 (mass-flow temperature
    compensation) to 0x3615 (differential-pressure temperature compensation) —
    the correct co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
    [captive_portal.cpp]
2026-08-15 fw 1.7.7-usb-dev: log SDP810 product identifier at boot
    1.7.6 fixed the init NACK (init now reports success) but the sensor still
    returns raw dp=-32768. CRC validation is verified correct against the
    datasheet's own worked example (CRC(0xBEEF)=0x92), so the I2C bus is clean
    and the part is genuinely reporting a rail value — this is hardware, not
    protocol.
    Read the product identifier (datasheet 6.3.6) at boot to confirm the part
    is alive and which SDP8xx variant is fitted, independent of whether its
    pressure element is sane. Bench diagnostic only.
    [captive_portal.cpp]
2026-08-15 fw 1.7.8-usb-dev: correct product-id read (stop continuous first, check CRC)
    1.7.7 read the product identifier while the sensor was still in continuous
    measurement mode, so it returned measurement frames rather than the ID —
    the resulting 0x00F001E0 was my read error, not a real part number.
    - Send stop-continuous (0x3FF9) before the 0x367C/0xE102 sequence
    - Validate all six CRC words of the ID frame before reporting, so a garbage
    read can never be misreported as a part number
    Expected for this hardware: 0x03020B01 (SDP810-125Pa), per datasheet 6.3.6.
    [captive_portal.cpp]
2026-08-15 fw 1.7.8-usb: release build — drop unreliable diagnostic, publish binaries
    Bench test passed end to end, so cut the release from this branch:
    - Remove the product-identifier diagnostic added in 1.7.7. It reported
    0x00F001E0 for the failed sensor and 0x00000000 for the known-good
    replacement, while the datasheet specifies 0x03020B01 for SDP810-125Pa —
    it misreads working hardware, so it cannot support any conclusion about
    a part's authenticity and is worse than having no check at all. The
    measurement CRC plus physical plausibility are the signals to trust.
    - Drop the DEBUG_SENSOR_RAW build flag (bench-only logging).
    - Version 1.7.8-usb (prod) / 1.7.8-usb-test (bare-board simula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
    [captive_portal.cpp]
2026-08-15 One-tap setup handoff, Fahrenheit UI, adaptive sampling fw v1.8.0, Next 15.2.9 (#29)
    Founder bench-test feedback round 2:
    - Setup handoff: the portal success page now shows a 'Finish setup'
    button whose link carries the Device ID (?device=SF...) — nothing to
    memorize or screenshot. The page survives the WiFi switch; the tap
    happens after the phone auto-rejoins home WiFi. Setup page also accepts
    ?id= (QR labels) in addition to ?device=.
    - All customer-facing temperatures now display in Fahrenheit (readings
    table, charts, dashboard cards, admin fleet) via src/lib/units.ts;
    storage stays Celsius.
    - Firmware v1.8.0 (atop local instance's v1.7.8 sensor fixes): adaptive
    sampling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
    [captive_portal.cpp]
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2026-08-20 Firmware v1.9.0: auto-recover from setup mode after power outages (#38)
    Field finding from the first real outage: the monitor boots back in
    seconds but the router takes minutes, so the ~65s join attempt fails
    and a configured unit sat in setup mode forever, gathering no data.
    A configured unit in setup mode now reboots and retries the join every
    5 minutes indefinitely until it reconnects. Any setup-portal activity
    (page load, scan, AP association) resets the clock so an active
    reconfiguration is never interrupted. Normal operation additionally
    enables WiFi auto-reconnect for transient drops. Binaries rebuilt in
    esp32/builds/ and OTA image published at public/firmware/.
    Claude-Session: htt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
    [captive_portal.cpp]
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2026-08-21 Firmware v1.10.0: presence-aware glow via Bluetooth proximity (#44)
    Passive NimBLE scan (observer role only, ~10% radio duty) watches for
    BLE advertisements from phones/wearables. RSSI >= -60 dBm marks someone
    nearby: status glow runs full brightness for 10 minutes, then settles
    to a 15% idle glow. Setup/connecting/error states always render at full
    brightness. Scan starts only in normal operation, never during the
    setup AP. Unused NimBLE roles stripped to keep the app image inside the
    OTA slot (93.5%). Binaries in esp32/builds/, OTA image published.
    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
    [captive_portal.cpp]
2026-08-21 Firmware v1.10.1: fix BLE scan memory leak (#45)
    * Firmware v1.10.1: fix BLE scan memory leak from v1.10.0
    The continuous scan stored every advertisement heard (NimBLE default);
    the results list grew until heap exhaustion killed the TLS connection
    to the API and readings silently stopped. setMaxResults(0) makes the
    scan callback-only. Also logs free heap with each successful send.
    * Docs: current build filenames in FLASHING.md
    ---------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
    [captive_portal.cpp]
2026-08-21 Firmware v1.10.2: duty-cycled BLE scan + self-healing watchdog (#47)
    v1.10.1's continuous scan still degraded networking within ~40 min in
    the field (heap fragmentation starving TLS handshakes). Structural fix:
    BLE scans in 3s bursts every 30s with a low-heap guard, and 5
    consecutive failed uploads trigger a self-reboot into the known-good
    boot path, so the monitor can never silently stop reporting regardless
    of root cause.
    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
    [captive_portal.cpp]
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2026-08-21 Firmware v1.10.3: park BLE presence, add hardware task watchdog (#49)
    v1.10.2 still froze solid after ~30-40 min in the field. A full hang
    never reaches the software send-failure watchdog, so the chip's
    hardware task watchdog now guards the main loop (300 s, panic reboot).
    BLE presence is compiled out until bench debugging over serial finds
    the real coexistence fault; the code remains behind ENABLE_PRESENCE.
    App image back to 80 percent of the OTA slot.
    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
    [captive_portal.cpp]
2026-08-21 Firmware v1.10.4: sensor faults visible and self-healing (#50)
    A mute sensor (loose jumper) froze both readings and lastSeen,
    indistinguishable from a dead device — it mimicked the BLE bugs all
    day. After 3 invalid reads the monitor now heartbeats /api/device/status
    with status 'error' every 60s (dashboard shows online + sensor fault),
    blinks the onboard LED at 5 Hz, and re-inits the sensor every 30s to
    self-heal flaky connections, reporting 'active' on recovery.
    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
    [captive_portal.cpp]
2026-08-21 Firmware v1.10.5: over-range pegged readings + fault reasons (#51)
    * Firmware v1.10.5: publish over-range as pegged readings, fault reasons
    Rail rejection (v1.8.0) has a second trigger besides a dead sensor: a
    healthy 125 Pa part whose blower-on dP exceeds ~136 Pa rails every
    reading, blacking out whole cycles in a way that perfectly mimics a
    wiring fault. CRC-valid rails with sane temperature now publish pegged
    at the range limit so the chart shows a flat ceiling instead of
    silence; rails with nonsense temperature still reject. Fault heartbeats
    carry the reason (error-nack/crc/temp) and the device page renders any
    error-* status red.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
    [captive_portal.cpp]
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2026-09-20 Firmware v1.12.0: batched uploads + deployed-commit health check (#71)
    Firmware: readings keep the same aggregation cadence (10 s active /
    60 s idle — identical cloud data resolution) but buffer locally and
    flush together in one POST /sensor/batch per minute, each carrying
    ageSeconds for exact server-side timestamps. Failed flushes keep the
    buffer (30-reading cap, oldest dropped) and retry next minute; the
    send-failure watchdog reboots after 5 failed flushes; first post-boot
    reading flushes immediately so the unit shows online right away. Cuts
    steady-state requests from ~6/min to 1/min — the dominant serverless
    compute cost and the thing that hit Vercel's free-tier ceiling.
    Server: batc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
    [captive_portal.cpp]
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
